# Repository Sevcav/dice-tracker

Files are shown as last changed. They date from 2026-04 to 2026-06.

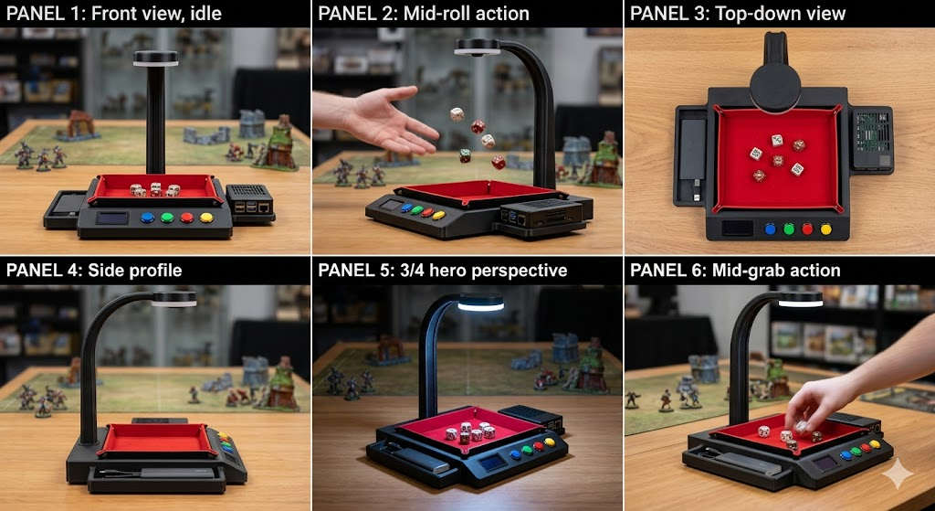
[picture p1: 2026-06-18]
docs/Concept.png

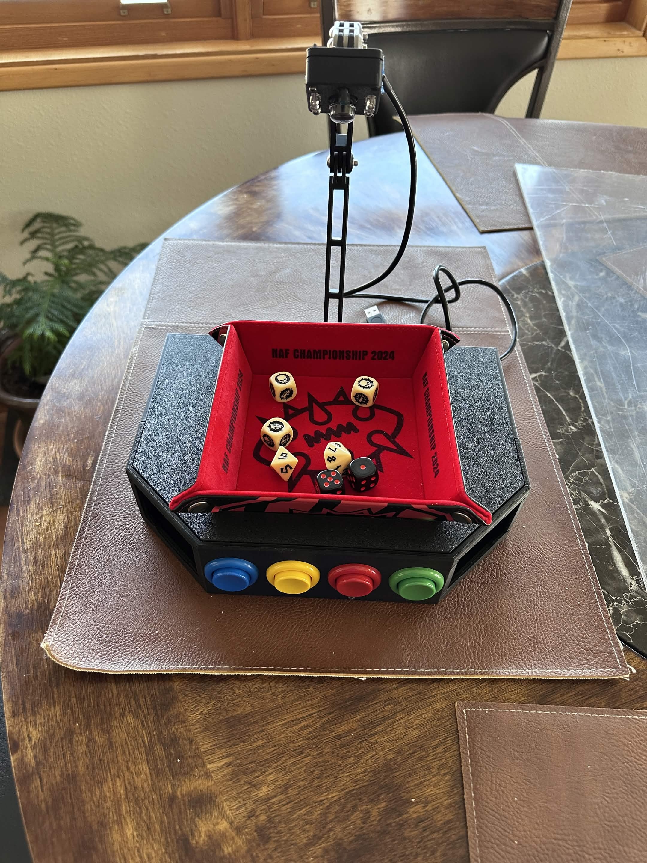
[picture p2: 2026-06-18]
docs/Completed Rig.jpg

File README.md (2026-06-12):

# Blood Bowl Dice Tracker

A portable dice-roll capture rig for Blood Bowl games and tournaments.
Players roll into a felt tray; a camera reads the dice with a YOLO model;
the rolling player confirms with a button; every roll is logged to a
database. At the end of the game you get a per-player, per-face dice
record (and the statistical proof that your dice really were cursed).

**Target hardware:** Raspberry Pi 4B + Arducam B0205 IR USB camera in a
3D-printed two-tier rig with 4 arcade buttons and 2 OLED displays.
Currently developed and validated on a Windows PC bench rig.

## How it works

1. `dice_tracker.py` watches the tray. A combined 27-class YOLOv11n
   model reads **block dice, d6, and d16 in one inference** — the dice
   type is identified automatically from the detected faces.
2. When the dice settle (stable count + stable labels), the read locks
   and the border flashes green. Low-confidence reads are flagged with
   an orange `?` — nudge that die and it re-reads in place.
3. Confirm logs the roll to SQLite under the active player. Reject saves
   the frame (with your correction) as future training data.
4. The phone web UI (`http://<rig-ip>:5000/`) shows the live read,
   switches dice type manually if ever needed, and serves the post-game
   record: face tallies per player, roll log, corrections, CSV export.

## Quick start (PC bench)

```
pip install -r requirements.txt
python dice_tracker.py            # alignment overlay -> SPACE -> play
python webapp.py                  # standalone review server (no camera)
python eval_harness.py --type block   # measure real per-die accuracy
```

Every camera session starts with two built-in pre-flights: an IR-mode
self-check (the models only know IR frames) and a tray-alignment overlay
(the models only know the calibrated perspective).

## Key documents

- **`DESIGN.md`** — single source of truth: hardware specs, detection
  architecture, locked decisions, lessons learned.
- **`HANDOFF.md`** — current state + next priorities for a new session.
- **`SETUP.txt`** — the original settle-then-confirm UX intent.

## Training

Labeling in Roboflow (free tier), training local via Ultralytics
(`training/train_all.py`, YOLOv11n). `training/merge_datasets.py` builds
the combined 27-class dataset from the per-type projects. Models export
to ONNX and transfer to the Pi by SCP (binaries are not committed).
Retraining policy: a new model must hit **mAP@50 ≥ 92%** on held-out
validation before it replaces production.

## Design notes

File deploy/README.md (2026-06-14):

# Raspberry Pi deployment

Move the tracker off the bench PC onto the portable rig. The Pi runs the
**torch-free** path automatically — same app, same logic, light deps.

## What makes the Pi path work

`inference_backend.py` picks the backend at import:
- **PC**: ultralytics + supervision (torch) — unchanged dev experience.
- **Pi**: `onnx_backend.py` — pure onnxruntime + numpy. Custom YOLOv11
  decoder, agnostic NMS, an IoU tracker (ByteTrack-equivalent) and a box
  smoother. Verified **bit-for-bit identical** detections to the
  ultralytics path on banked frames (2026-06-14).

`hardware.py` adds the 4 buttons / 4 LEDs / 2 OLEDs against the locked
pin map (DESIGN.md). It is a silent no-op when gpiozero/luma are absent,
so the same code runs on the PC.

## Headless operation (no monitor — the design)

The rig is a sealed box; the **phone is the only screen**. On the Pi,
dice_tracker runs HEADLESS automatically (no `$DISPLAY` and/or the onnx
backend) — no OpenCV window ever opens. Control + alignment happen on the
phone, plus the physical GPIO buttons:

- **Alignment:** open `http://dicetracker.local:5000/align` on the phone.
  It shows the live camera feed with the green tray outline; adjust the
  arm until they match, tap **Confirm alignment**. (Always step one — the
  model only knows the calibrated perspective.)
- **Live view + control:** the main phone page shows the live read and the
  dice-type / player controls; Reject / Undo / Confirm are available from
  the phone, and the arcade buttons do the same.
- `--gui` forces the dev preview window on a PC with a display; `--headless`
  forces headless anywhere.

## First bring-up

1. On the PC, push the latest code + the deployed model:
   ```
   git push                       # already done from the PC
   ```
2. On the Pi:
   ```
   git clone https://github.com/Sevcav/dice-tracker.git   # or git pull
   cd dice-tracker
   bash deploy/setup_pi.sh
   ```
   The script: apt deps, enables SPI, builds a venv with
   `requirements-pi.txt`, verifies `BACKEND == onnx`, sets the
   `dicetracker.local` mDNS hostname, lists camera devices.
3. Copy the model if not in git (ONNX is gitignored):
   ```
   scp training/models/combined.onnx        sevcav@dicetracker.local:~/dice-tracker/training/models/
   scp training/models/combined.onnx.json   sevcav@dicetracker.local:~/dice-tracker/training/models/
   ```
4. Run (headless is automatic on the Pi):
   ```
   . .venv/bin/activate
   python dice_tracker.py
   ```
   Then on the phone:
   - `http://dicetracker.local:5000/align` → align the camera, Confirm
   - `http://dicetracker.local:5000/` → live read + controls

## Autostart at boot (optional)

```
sudo cp deploy/dice-tracker.service /etc/systemd/system/
sudo systemctl enable --now dice-tracker
journalctl -u dice-tracker -f      # watch logs
```

## Checklist when something's off

- `python -c "import inference_backend as b; print(b.BACKEND)"` must print
  `onnx`. If it prints `ultralytics`, torch leaked into the venv — the Pi
  will try to load torch and choke.
- Buttons/LEDs dead? `python hardware.py` prints GPIO/OLED availability and
  the pin map; check the user is in the `gpio`/`spi` groups.
- OLEDs blank? Confirm SPI is enabled (`ls /dev/spidev*`) and both CE0/CE1
  are wired.
- Camera not found? `v4l2-ctl --list-devices`; the USB camera (not the
  dead CSI ribbon) is the path.
- Reads bad? It's almost always alignment or day-mode — the startup
  self-checks catch both; match the green outline and confirm IR mode.

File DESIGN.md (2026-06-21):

# Blood Bowl Dice Tracker — Design Document

**Last updated:** June 15, 2026
**Status:** **LIVE ON THE PORTABLE PI RIG (headless).** The synthetic-data
retrain shipped (live: block 100% / d6 100% / d16 85%, pow 60%→100%) and
the whole system now runs on the Pi off-camera through the torch-free ONNX
backend — buttons, LEDs, dual OLEDs all confirmed. Currently polishing the
first live run (d16 settle fix + LED dimming, pushed 2026-06-15, awaiting
final live confirm). **See HANDOFF.md "LIVE RIG BRING-UP" for the exact
resume point.** Models: production `combined.onnx` = full-rotation
tray-crop 27-class YOLOv11n + `combined.onnx.json` sidecar (tray_crop,
pad 8 / pad_bottom 40). Pi: `dicetracker`@192.168.68.85, user `sevcav`,
run via `cd ~/dice-tracker && . .venv/bin/activate && python dice_tracker.py`.

*(Prior bench-rig status, still true: auto dice-type detection, settle-race
fix COUNT_STABLE_FRAMES, IR self-check + alignment pre-flights.)*
SQLite database + phone web app live: dice-type control, live read
display, post-game corrections (dropdowns), CSV export, and the
**BB3-style end-of-game dice record** with icons drawn from the actual
dice. All committed + pushed. See `HANDOFF.md` for the session hand-off
prompt, and memory entity `BB Dice Tracker Current State 2026-06-12`.

**Retraining policy (locked):** Any retrain (block / d6 / d16) using accumulated rejection frames must still achieve **mAP ≥ ~92%** (block baseline) on the held-out validation set before its ONNX replaces the production model. If retrain regresses below baseline, do not deploy — revert and try a different mix of training data.

**Combined model + auto dice-type detection (deployed 2026-06-11):**
manual dice-type switching proved unworkable in play (players alternate
block/d6 constantly; a wrong-model read logs confident garbage). Cheap
discriminators failed offline (confidence-vote 73%, brightness
inconclusive), so the original single-combined-model plan was revived:
the three datasets were merged (`training/merge_datasets.py`, 1126
images, 27 classes) and one YOLOv11n trained locally. Per-type mAP@50 vs
the separate models: block 92.4% (−3.7, still over the 92% bar), d6
98.4% (−1.1), d16 87.4% (−1.1). `dice_tracker.py` defaults to **auto
mode** (`combined.onnx`): dice type is derived from the detected face
labels per roll; per-type models remain as manual overrides (keys
B/D/X, phone buttons). Pi cost unchanged — one nano inference per frame.

**Session startup rule (locked 2026-06-11):** **Camera alignment is ALWAYS the first step of any camera session.** Moving the rig moves the camera, and the models only know the calibrated tray perspective in `tray_roi.json`. Never score, capture, or log rolls before alignment is confirmed. On the PC (GUI) this is the on-screen green-outline overlay → SPACE; on the **headless Pi** it is the phone alignment screen (`/align`: live feed + green outline → Confirm). Standalone `align_camera.py` remains for bench work.

**Headless rule (locked 2026-06-14):** **The production rig has NO monitor — it is a sealed box and the phone is the only screen.** `dice_tracker.py` runs headless automatically on the Pi (no `$DISPLAY` / torch-free onnx backend): no OpenCV window ever opens; alignment, live read, and Reject/Undo/Confirm are all on the phone, alongside the 4 GPIO buttons. The cv2 preview window is dev-only (`--gui` on a PC). Do not reintroduce a runtime dependency on an attached display.

---

## 1. Project Vision

A portable, self-contained device that captures Blood Bowl dice rolls at gaming
stores and tournaments. Players roll into a tray, the camera reads the dice,
the result is attributed to the rolling player via a dedicated button, and the
roll is logged to a database for later analysis via a web app.

**Not a livestream/replay device.** A **data capture device**.

### Core requirements

- Self-contained — no PC on the table
- Works under variable lighting (gaming store conditions)
- Powered by USB power bank for portability
- Modular 3D-printed rig (lower tier + lid + removable dice tray + power bank shelf)
- Phone connects over WiFi for the web UI

---

## 2. Production Rig Design (Active)

The production rig is a **modular two-tier design** with a removable dice tray.

### Architecture

| Tier | Purpose |
|---|---|
| **Lower tier** | Electronics enclosure — Pi, buttons, LEDs, OLEDs, camera mount |
| **Lid** | Sits on top of lower tier, has tray opening + posts hanging down to bolt to lower tier |
| **Dice tray (removable)** | Drops into the lid's tray opening, felt-lined, removable for felt application and Pi access |
| **Power bank shelf** | External, attaches to rear of rig |

### Outer Dimensions

- **Outer footprint:** 260 × 190mm (W × D) with 55 × 55mm chamfered front corners
- **Lower tier height:** 60mm
- **Lid height:** 60mm
- **Total stack height:** 120mm + tray protrusion

### Material

- **PETG** throughout (heat resistance for hot summer venues)
- 4mm wall thickness on all major shells

---

## 3. Component Status

| Component | Status | Notes |
|---|---|---|
| **Lower tier** | ✅ Modeled | All cuts complete: buttons, LEDs, OLED windows, camera mount |
| **Lid (with posts)** | ✅ Modeled | Tray opening + 4 hanging posts with captive M4 nuts |
| **Dice tray (removable)** | ⏳ To design | Felt-lined insert, drops into lid tray opening |
| **Camera base plate** | ⏳ To design | Replaces MakerWorld Camera_Base bottom; bolts into lower tier rear detent |
| **Power bank shelf** | ⏳ To design | External rear shelf for UGREEN power bank |
| **Camera cradle** | 🔧 Blocked | Need Arducam in hand for pocket sizing |
| **Photoresistor light shield** | ✅ Printed | Black cover over the B0205 photoresistor forcing IR mode. NOTE: frame analysis 2026-06-11 found the May 13 *morning* session ran in day mode (color cast) while the afternoon ran in IR — verify the shield fully seals against bright-room light |
| **Bench prototype tray cradle** | ✅ Printed | Standalone test, validated soft-tray support concept |
| **Bench prototype arm foot** | ✅ Printed | Bridges over cradle back posts; captive nuts; friction-fit |
| **Camera_Base + Camera_Link** | ✅ Printed | From MakerWorld 627829, will be re-used for production rig |

---

## 4. Production Rig — Detailed Specs

### 4.1 Lower Tier

| Spec | Value |
|---|---|
| Outer footprint | 260 × 190mm with 55mm front chamfers |
| Wall thickness | 4mm |
| Height | 60mm |
| Front face: button holes | 4 × Ø27.78mm |
| Front face: LED holes | 4 × Ø8mm (for 7.5mm snap-in bezels) |
| Button positions (X) | ±56.7 and ±18.9mm |
| Button vertical (Z) | ~33mm centered |
| LED positions (X) | Same as buttons |
| LED vertical (Z) | ~9mm |
| Both chamfered corners | OLED window (62.53 × 40.28mm) + PCB recess (3mm deep) |
| Rear face: camera mount detent | 50 × 50 × 3mm pocket on outside |
| Rear inside wall: nut pockets | 4× hex pockets, 0.25mm deep, on inside of rear wall |
| Rear bolt clearance | 4 × Ø4.5mm holes through rear wall |
| Camera mount bolt path | Outside (camera plate) → through 4.5mm clearance → into captive nut on inside |

### 4.2 Lid

| Spec | Value |
|---|---|
| Outer footprint | 251.44 × 181.44mm with chamfered front corners (matches lower tier outline) |
| Wall thickness | 4mm |
| Height | 60mm |
| Tray opening (visible from top) | 160mm wide × 130mm deep |
| Tray opening lip | 4mm wide step around perimeter, 2mm deep recess |
| Tray opening biased toward rear | Yes |
| Posts (4) | Round Ø10mm columns hanging from lid underside |
| Post length | 54mm (engages 2mm into lower tier floor pocket) |
| Post positions | Front: (±110, -30); Rear: (±115, +85) |
| Post captive nut | M4 hex pocket at bottom of each post (3.4mm deep) |
| Post bolt clearance | Ø4.5mm hole through center of each post |
| Bolt entry | From bottom of lower tier (countersunk) |

### 4.3 Dice tray (still to design)

| Spec | Value |
|---|---|
| Outer flange (sits on lid lip) | 159.7 × 138.7mm × 2mm tall |
| Tray body (drops through lid) | 153.7 × 132.7mm |
| Total height | ~52mm |
| Wall thickness | 4mm |
| Floor thickness | 3mm |
| Inner draft | 5° outward (top wider) |
| Felt lining | Self-adhesive felt sheet, applied after print |

### 4.4 Camera base plate (still to design)

| Spec | Value |
|---|---|
| Plate size | ~50 × 50mm (sized to fit in 50×50mm rear detent of lower tier) |
| Plate thickness | 3mm (recessed flush into detent) |
| Top mating | Hinge clevis matching Camera_Link's M4 hinge |
| Bottom mating | 4× M4 clearance holes matching lower tier captive nut pattern |

### 4.5 Power bank shelf (still to design)

| Spec | Value |
|---|---|
| Power bank dimensions | 160.5 × 81 × 26.5mm (UGREEN Nexode) |
| Shelf attachment | Snap-fits or bolts to rear face of lower tier |
| Cable management | Routes USB-C power to rear of rig into Pi |

---

## 5. Detection Software

### Pipeline (current — YOLO architecture)

1. **Frame capture** — `capture_frames.py` saves raw 1280×720 frames in IR mode
2. **Stability tracker** — wait for dice to settle (no motion) — to be carried over from old code
3. **YOLO inference** — single ONNX model produces per-die `(class, x, y, w, h, conf)` boxes
4. **Player attribution** — handled at the rig (see Player attribution section)

The legacy rule-based pipeline (mask → contours → watershed → CNN classifier)
has been **archived** under `archive/legacy_rule_based_detector/`.
See that folder's README.md for why it was abandoned.

### Dice scope

| Die | Detection | Classes | Status |
|---|---|---|---|
| Block dice (cream) | YOLO | 5 (pow, push, both_down, player_down, stumble) | ✅ Labeled, training overnight 5/4 |
| BB d6 (black) | YOLO | 6 (1-5, bb_logo) | ⏳ After block validates |
| D16 (cream, trapezohedron) | YOLO | 16 (1-16) | ⏳ After d6 — injury rolls |
| D8 (scatter) | 📱 Manual entry on phone | — | — |
| D3 | 📱 Manual entry on phone | — | — |

**Single combined model is preferred** — one YOLO model with all classes vs.
separate models per die type. Easier deployment, single inference call. We
will train block-only first to validate the workflow, then expand the same
model to include d6 then d16.

### Camera angle

Set **empirically** by functional constraints (full tray visible + arm clear
of rolling area), not to a fixed degree number. As-built geometry comes out
shallow / near-overhead — top faces dominate each die crop, side faces are
minimized. The "~35° forward bank shot" figure from earlier docs was an
estimate that did not match the as-built rig.

### Lighting / IR

Production lighting strategy is **forced IR mode** on the Arducam B0205.
This eliminates color/white-balance variability across gaming store
conditions, and IR LED illumination dominates ambient light from windows
and store fluorescents — making the dice appearance consistent regardless
of time of day.

The B0205's IR mode is **photoresistor-controlled only** (no software
toggle available). A 3D-printed light shield over the photoresistor will
force IR mode on regardless of room brightness — see Section 3 component
list.

> **VERIFIED 2026-06-21 (UVC enumeration on the Pi).** `v4l2-ctl
> --list-ctrls-menus` and `uvcdynctrl -c` against `/dev/video0` return only
> the stock OV2710 UVC control set (brightness, contrast, saturation, hue,
> white balance, gamma, gain, power-line-freq, sharpness, backlight
> compensation, auto-exposure, exposure time). **No IR / night / day /
> IR-cut control and no vendor extension units exist.** There is therefore
> no software path to force the IR-cut filter — confirming this decision.
> Do not re-open "replace the camera software to force IR"; the firmware
> does not expose the filter. The day-mode self-check is healthy and **auto-white-balance is load-bearing
> for IR detection.** Measured + VISUALLY CONFIRMED 2026-06-21 (tracker
> stopped, `/dev/video0`, rig in a sunlit window, shield sealed): saved
> frames `sun_awb_on.jpg` / `sun_awb_off.jpg` show the SAME dark IR scene —
> no daylight floods the sensor (shield works). With **AWB ON** the raw
> violet IR cast is corrected to near-neutral → `color_dev` **3.58** (reads
> IR, correct). With **AWB OFF** the identical scene goes strongly purple
> (OV2710 raw channel imbalance in near-IR) → `color_dev` **11.84** → false
> day-mode, against the `DAY_MODE_DEVIATION = 8.0` threshold.
>
> Therefore: **do NOT pin `white_balance_automatic=0`** — AWB-on is what
> keeps IR frames neutral; disabling it BREAKS the day-mode check. Leading
> hypothesis for the intermittent real-world day-mode trips: the live
> re-check (`dice_tracker.py` ~L753, `IR_CHECK_INTERVAL`) sampling during a
> window where **AWB has not yet converged** (just after open, or after a
> lighting change) and briefly seeing the raw violet cast. To confirm: log
> `color_dev` + save the frame on every re-check trip over a real session.

### Roboflow + training workflow

- **Dataset:** Roboflow Public/Free workspace `bbdicetracker`
- **Project:** "My First Project" (Object Detection, public)
- **Capture script:** `capture_frames.py` saves 1280×720 frames to
  `capture_sessions/<timestamp>/`
- **Labeling:** Roboflow web UI, manual bounding boxes per die
- **Preprocessing:** Auto-Orient, Resize 640×640
- **Augmentation:** Horizontal flip, ±15° rotation, ±20% brightness,
  ≤1px blur, ≤1% noise
- **Train/val/test split:** 70/20/10 (112/32/16 of the 160 frames)
- **Model:** Roboflow 3.0 Object Detection (Fast variant)
- **Checkpoint:** Fine-tune from MS COCO
- **Deployment:** ONNX export → `classifier/` folder → ONNX Runtime on Pi
  (already validated)

### Player attribution

- 4 buttons on rig: **P1 Confirm**, **P2 Confirm**, **Reject**, **Undo**
- Whoever pressed **their** confirm button = the rolling player
- No turn tracking on rig — that lives in the web app
- Phone web app selects dice type (Block / D6 / D16) before each roll

### Correction flow (LOCKED 2026-05-13)

The rig has **4 buttons total**. There is **no keyboard, no number-pad,
no menu navigation** during play. Players will abandon any correction
tool that takes more than a button press. This drives a hard design
principle: **prevention over correction**.

**Pre-confirm correction tools (real-time, frequent use):**

1. **Nudge to re-read** — player physically nudges a misread die.
   `dice_tracker.py` detects per-die motion of more than
   `NUDGE_PIXEL_THRESHOLD = 20px` between consecutive frames and
   automatically releases the settle lock back to "watching" so the
   model re-evaluates. The rest of the roll is preserved; only the
   nudged die gets re-read. Built and validated.
2. **OLED uncertainty markers** *(planned)* — low-confidence labels
   shown with a `?` so the player's attention is drawn to questionable
   dice. High-confidence labels show clean. The OLED's role is to
   make wrong-reads obvious BEFORE the player confirms.
3. **Reject button** — explicit "this read is wrong" before confirm.
   Saves the frame to `retrain_candidates/<type>/` for future model
   improvement.

**Post-confirm correction tools (emergency, rare use):**

4. **Undo button** — removes the LAST logged roll. Player must catch
   the mistake immediately (within ~1 roll). If they realize N rolls
   later, Undo would lose the rolls in between.
5. **Phone web app post-game session review** *(planned, post-MVP)* —
   the phone app's session export/review screen will allow editing
   historical mis-logged rolls. This is the only path for corrections
   discovered late. It is explicitly NOT a real-time tool — it's run
   after the game when speed doesn't matter.

**What we deliberately did NOT build:**

- No keyboard-driven edit flow (`E` to enter manual values for last
  roll) — violates the 4-button constraint and the "no menus" rule.
- No mid-game phone-based correction — adds a context switch that
  slows play; players abandon the tool.
- No "undo by roll number" — too complex for buttons; ambiguous which
  intermediate rolls to preserve.

The cost of this constraint: occasional wrong rolls slip into the log
and aren't caught until later. That is acceptable as long as the
model + OLED-warning + nudge UX keeps the slip rate low. If real-world
play shows the slip rate is too high, the fix is more training data
(retrain to a higher mAP) or richer OLED warning — NOT a richer
correction UI on the rig.

### Accuracy evaluation (added 2026-06-11)

`eval_harness.py` measures **real per-die accuracy** against keyed-in ground
truth, using the exact production detection stack from `dice_tracker.py`.
Per roll: settle → console prints the read (dice numbered left→right,
matching `[n]` overlays in the window) → user types truth (ENTER = correct)
→ clear tray → repeat; `q` prints + saves the report
(`eval_sessions/eval_<type>_<ts>.json/.csv`). Misread frames are saved to
`retrain_candidates/<type>/eval_miss_*.jpg/.json` **with ground truth
attached**, ready for relabeling. The report includes per-die accuracy with
a 95% Wilson CI, roll-level accuracy, per-class recall, confusion pairs,
detection-count errors, and how many rolls were captured in day mode.

Target: ≥50 rolls per dice type (~±3-4% CI at 3 dice/roll). The previous
"86% confirm rate" was 6/7 rolls — 95% CI of 49-97%, not a usable number.

**First block eval (2026-06-11, 50 rolls, 144 dice, all IR):**

- Per-die accuracy 86/96 = **89.6%** (95% CI 81.9–94.2%) on count-correct
  rolls; roll-level 79.4%.
- **Dominant failure: missed dice** — 16/50 rolls lost dice (23 dice never
  read). ROOT CAUSE FOUND: a settle-logic race, not model blindness —
  14/16 saved miss-frames had ALL dice detectable at standard settings on
  the very frame that settled. A detection flickering in/out at the conf
  threshold let the roll settle during an "out" frame. **Fixed** by
  requiring the detection count to hold constant for
  `COUNT_STABLE_FRAMES = 10` consecutive frames before settle (restores
  the count-stability requirement the legacy DiceStabilityTracker had).
  Needs re-eval to confirm.
- Weakest class: **pow, 64% recall** (7/11), confused with stumble ×3.
  More pow training data wanted at next retrain.
- **Confidence threshold 0.85 validated for OLED `?` markers**: 8/10
  wrong reads fell below 0.85; only 18/86 correct reads did.
- The 2 miss-frames not recovered at conf 0.40 full-frame WERE recovered
  by a tray-ROI crop — keep tray-crop inference in the back pocket as an
  accuracy lever.

**Re-eval after settle fix (2026-06-11, 25 rolls, 75 dice):**

- **Count errors collapsed: 16/50 → 2/25** (32% → 8%). Settle-race fix
  validated.
- Per-die accuracy 57/69 = 82.6% (CI 72.0–89.8%) — *lower* than session 1
  because the hard flickery dice that previously vanished as count errors
  now stay in the read and get scored. This is the honest number.
  Combined across both sessions: 143/165 = 86.7%.
- **pow recall 57%** (8/14); combined 15/25 = 60%. pow confusions go both
  directions (read as both_down ×3, stumble ×2). Every other class is
  86–97%.
- **Misread-frame experiment:** re-reading the same frames full-frame fixed
  0/10 (errors are systematic, not flicker). Tray-crop re-read flipped pow
  to CORRECT in 4 rolls — pow is distinguishable at 2× resolution — but
  broke other dice because the model wasn't trained on crops.
- **Conclusion / retrain plan:** the pow fix is RESOLUTION, i.e. retrain
  on tray-cropped data and run inference on crops. Next capture session:
  pow-heavy + wall/corner positions; build the dataset tray-cropped
  (training is local now, we control preprocessing); fold in the banked
  `retrain_candidates/block/` frames with ground truth. ≥92% mAP bar
  applies. Until then the current model stays in production — the 0.85
  OLED `?` threshold catches ~80% of its wrong reads.

Both `dice_tracker.py` and `eval_harness.py` now run two startup
pre-flights, in order:

1. **IR-mode self-check** — refuse-to-start prompt in day mode;
   `dice_tracker.py` also re-checks every ~3s during play with a red HUD
   warning if the camera flips to day mode mid-session.
2. **Camera alignment check** — overlays the saved tray-corner reference
   (`tray_roi.json`) on the live feed; adjust the camera arm until the
   tray matches the green outline, SPACE to continue. The rig moves
   between sessions and the model only knows the calibrated perspective,
   so this always runs first (standalone `align_camera.py` still exists
   for bench work).

### Database + web app (IMPLEMENTED 2026-06-11)

**`db.py`** — SQLite (`dice_tracker.db`, gitignored), short-lived
connections (safe across tracker + Flask threads):

```
games:  id, started_at, ended_at, player1_name, player2_name, notes
rolls:  id, game_id FK, roll_no, timestamp, player (P1|P2), dice_type,
        results JSON, confidences JSON, rejected, edited, raw_image_path
```

`dice_tracker.py` creates the game row lazily on the first logged roll,
inserts on confirm AND reject (rejected=1), deletes on undo, closes the
game on quit. `face_tallies()` produces THE end-of-game record:
per-player, per-dice-type face counts over confirmed rolls.

**`webapp.py`** — Flask phone UI, mobile-first, single file:

- **Live control** (`/`): dice-type buttons (Block/D6/D16) and active
  player buttons; requests flow to the tracker loop through a
  thread-safe `WebControl` mailbox; 1s status poll (state, last roll,
  roll count, day-mode warning).
- **Game review** (`/games`, `/games/<id>`): roll log with confidences +
  reject/edit flags, the face-tally record, per-roll edit (flagged
  `edited` — this is the post-game correction path from the locked
  correction flow), delete, CSV export.
- Started automatically in a daemon thread by `dice_tracker.py` on port
  5000 (`--no-web` disables). Standalone review mode: `python webapp.py`.

**HUD uncertainty markers (OLED precursor, threshold 0.85 from eval
data):** stable+confident = yellow; stable but conf < 0.85 = ORANGE with
`?` and a NUDGE hint; still settling = gray. The same three-state logic
will drive the physical OLEDs.

---

## 6. Hardware

### As-built BOM (components actually used in the rig)

- Raspberry Pi 4B in TH3D aluminum case (91 × 65 × 33mm)
- 64GB A2 microSD (upgraded from the original 32GB, which was getting full)
- Arducam 1080P Day/Night IR USB camera (OV2710 sensor) — the production
  camera; forced into IR mode by a printed lens cap over the photoresistor
- 4× WMYCONGCONG arcade buttons (verified: thread Ø26.25mm, dial Ø33mm, body
  length 62mm — using Ø27.78mm holes for print clearance)
- 4× 5mm pre-wired LEDs in 7.5mm snap-in bezels (Ø8mm holes); inline
  resistor under heatshrink on the red lead (status LEDs: P1/P2/reject/undo)
- 2× HiLetgo SPI 2.42" OLED 128×64 (SSD1309, 7-pin SPI): PCB 71×43mm, glass
  62.25×40mm, header zone 14mm at top
- UGREEN Power Bank (160.5 × 81 × 26.5mm)
- Dupont female-to-female jumper wires (OLED / button / LED GPIO wiring)
- 1-to-2 wire splitters (ground consolidation to the Pi's GND pins — see
  the Ground consolidation note below)
- M5×25mm SHCS + M5 nyloc nuts (camera arm friction joints)
- M3 + M4 screws (M4 lengths: 8/12/16/20mm) + M3/M4 nuts (case assembly)

### Optional add-on

- 7" HDMI touchscreen — on-rig display (Mediatrix MPI7002, runs at 1920×1080;
  desktop scaled to 2× for readability via labwc autostart `wlr-randr`). Handy
  for on-rig use but NOT required — the rig is normally controlled phone-only.

### Ordered but NOT used

- M4 brass heat-set inserts (kept for a future production revision)
- Bambu LED Lamp Kit 001 ×2 — was for the abandoned day-mode lighting
  strategy; the rig is **always IR** (see §6 Lighting / IR), so the lamps
  are unused
- Pre-crimped JST pigtails (5 red / 5 black) — replaced by Dupont jumpers
  + 1-to-2 splitters (wrong connector type for the OLED pin strip anyway)

### Equipment (tools / spares, not consumed in the build)

- Bambu P1S 3D printer
- Pi 3B (spare)
- Pi Camera v2.1 with 22" ribbon (CSI port non-functional on this Pi 4 —
  superseded by the USB Arducam)
- USB camera (test only, not the production camera)

### Wiring notes

- **OLEDs (SSD1309, SPI, 7-pin):** All 7 pins used. Two OLEDs share CLK/MOSI/DC/RES/VCC/GND; differentiated by CE0 (GPIO 8) and CE1 (GPIO 7). Requires ~20 female-to-female dupont jumper wires — **not yet on hand**.
- **LEDs:** Pre-wired with resistor inline under heatshrink on red lead. Connect red → GPIO, black → GND directly. No additional resistors needed.
- **Arcade button switches:** PCB-mount microswitch (pin legs, not spade). Use COM + NO only (ignore NC). Solder wires direct to pins or friction-fit female dupont. 2 wires per button × 4 buttons = 8 connections.
- **GPIO allocation:** OLEDs ×2 = 6 pins; Buttons ×4 = 4 pins; LEDs ×4 = 4 pins. Total = 14 of 28 available GPIOs.
- **Library:** luma.oled (pip install luma.oled) — native SSD1309 SPI support.

#### LOCKED GPIO pin map (2026-06-13, BCM numbering)

Verified software-clean (no SPI-bus collision; all plain GPIO with usable
internal pull-ups). OLEDs share the SPI0 bus, distinguished by chip-select.

| Function | BCM GPIO | Physical pin | Wiring |
|---|---|---|---|
| OLED SCLK (both) | GPIO 11 | 23 | SPI0 SCLK, shared |
| OLED MOSI/DIN (both) | GPIO 10 | 19 | SPI0 MOSI, shared |
| OLED DC (both) | GPIO 9 | 21 | shared |
| OLED RES/RST (both) | GPIO 25 | 22 | shared |
| OLED-1 CS (P1 side) | GPIO 8 | 24 | SPI0 CE0 |
| OLED-2 CS (P2 side) | GPIO 7 | 26 | SPI0 CE1 |
| OLED VCC (both) | 3V3 (NOT 5V) | 1 | shared; SSD1309 is a 3.3V part |
| OLED GND (both) | GND | 6 (any GND) | shared rail |
| Button: P1 Confirm | GPIO 17 | 11 | switch → GND, internal pull-up |
| Button: P2 Confirm | GPIO 27 | 13 | switch → GND, internal pull-up |
| Button: Reject | GPIO 22 | 15 | switch → GND, internal pull-up |
| Button: Undo | GPIO 23 | 16 | switch → GND, internal pull-up |
| LED: P1 | GPIO 5 | 29 | red → GPIO, black → GND (inline R) |
| LED: P2 | GPIO 6 | 31 | red → GPIO, black → GND (inline R) |
| LED: Reject | GPIO 13 | 33 | red → GPIO, black → GND (inline R) |
| LED: Undo | GPIO 19 | 35 | red → GPIO, black → GND (inline R) |

Buttons: COM/NO only (NC unused). LEDs already have inline resistors —
no external resistor. Convenient grounds (all the same rail): physical
pins 6, 9, 14, 20, 25, 30, 34, 39.

OLED VCC = **3V3 (pin 1)**, never 5V. GND = any ground pin above.

#### Ground consolidation (REVISED 2026-06-14 during wiring)

**ACTUAL APPROACH BEING WIRED: grounds go DIRECT to the Pi's 8 ground
pins using 1-to-2 Dupont splitters — the breadboard is NOT needed for
grounds.** 10 grounds (2 OLED + 4 button + 4 LED) vs 8 Pi ground pins
(6, 9, 14, 20, 25, 30, 34, 39); the user has 1-to-2 splitters, so a few
pins fan out to cover all 10. Rationale: for a sealed/portable rig,
direct-to-header has fewer friction joints to shake loose than a
breadboard rail, and the 8 ground pins have no other use. The ordered
breadboard becomes optional (spare, or a 3V3 rail for the two OLED VCC).

- **OLED grounds (both):** one Pi GND **pin 25** → 1-to-2 splitter →
  both OLED GNDs (pin 25 sits in the OLED signal cluster 19/21/22/23).
- **Buttons + LEDs (8 grounds):** spread across the remaining ground
  pins (6/9/14/20/30/34/39) with splitters as needed.

The breadboard option below is RETAINED as fallback / 3V3-rail use:

~10 ground wires, all **26–28 AWG Dupont-terminated**; case is already
set/printed (NO HAT — a GPIO terminal HAT stands too tall and covers the
header), stay plug-in (no cutting Dupont ends, no soldering), plenty of
internal room.

- **ORDERED 2026-06-14: REXQualis/Ambberdr 400-point self-adhesive
  breadboard** (Amazon's Choice, ~$7.19, 6-pack; 3.22×2.12×0.35"). This
  is the committed ground/3V3-bus part. Listing confirms
  the three musts: "2 Positive & Negative Power Lines on both ends" (the
  common bus), "Self-Adhesive Tape on the Back" (peel-stick mount), and
  "20-29 AWG" wire support (covers the 26–28 AWG Dupont). 170-point minis
  were REJECTED — they have no power rails (only 5-hole tie columns), so a
  10-wire bus would need bridging multiple columns.
  Wiring: stick it inside the rig; jumper any Pi GND pin
  (6/9/14/20/25/30/34/39) into a `-` power line to make it common ground;
  plug all 10 ground Duponts into it. One Pi GND pin used. The `+` line
  buses the two OLED **3V3** wires the same way (jumper from pin 1).
  Note: 400-pt rails are usually split into 2 segments/side — one short
  jumper joins the halves if you ever need >1 segment (you won't for 10).
  NEED ONE F/M jumper for the Pi-pin→rail link (female onto the Pi male
  header pin, male into the breadboard).
- **Rejected:**
  - GPIO screw-terminal HAT — covers the 40-pin header and stands too
    tall for the finished case; also needs Dupont ends cut to bare wire.
  - WAGO 221 lever-nuts — rated 24 AWG min; Dupont (26–28 AWG) too thin
    to seat. (WAGO 243 micro fits but needs cutting.)
  - 2.54mm common-bus PIN board — would work and stays plug-in, but the
    mini breadboard is cheaper/more flexible and we have the room.
- Portability caveat: breadboard rails are light friction tie-points —
  after seating, a dab of hot glue over the inserted wires (NOT solder,
  not on the rail clips) stops them backing out when the rig travels.
  Reversible with a peel.

NOTE on the generated wiring images (wiring/): the labels are verified
against THIS table, but the `wiring/gpio_wiring_diagram.png` v2 image has
one hallucinated label — "GND (Pin 7)". Physical **pin 7 is GPIO4, not a
ground.** Ignore that label and its dangling wire. This table is the
authoritative source, not the image.

### Captive nut pocket dimensions (PETG, 0.28mm gap)

| Nut | Circumscribed dia (Fusion polygon) | Flat-to-flat | Depth |
|---|---|---|---|
| M4 | 8.32mm | 7.56mm | 3.4mm |
| M5 | 9.80mm | 8.56mm | 4.1mm |

- Camera arm friction joints use M5×25mm SHCS + M5 nyloc nuts (M5×20 button heads too short — 5mm deficit at 16.5mm joint span)
- M5 bolt clearance hole: 5.7mm

---

## 7. Software State

### Pi-side stack (validated working)

- Python 3.13.5
- OpenCV 4.13.0
- ONNX Runtime 1.25.1
- Flask 3.1.1

### Code repo

- GitHub: github.com/Sevcav/dice-tracker
- Pi clones from this repo
- ONNX model transferred via SCP (binary, not committed to git)

### Repo layout (current, 2026-06-12)

```
Dice Code/
├── DESIGN.md                # This document — single source of truth
├── HANDOFF.md               # Session hand-off prompt + current priorities
├── README.md
├── SETUP.txt                # Original UX intent (settle→confirm) — still canon
├── requirements.txt
├── dice_tracker.py          # PRODUCTION app: YOLO + supervision stack +
│                            #   settle/confirm UX + DB logging + web thread
├── eval_harness.py          # Ground-truth per-die accuracy measurement
├── db.py                    # SQLite layer (games/rolls, face tallies)
├── webapp.py                # Phone web UI: live control + game record/review
├── dice_types.py            # Shared face vocabularies / type mapping
├── align_camera.py          # Standalone camera-alignment overlay
├── calibrate_tray_roi.py    # (Re)writes tray_roi.json reference corners
├── capture_frames.py        # Frame capture for labeling sessions
├── scan_capture.py          # Pre-upload capture QA (Roboflow ingest checks)
├── tray_roi.json            # Calibrated tray corners (may4 backup alongside)
├── training/                # Local Ultralytics training (RTX 4080)
│   ├── train_all.py         #   block / d6 / d16 / combined configs
│   ├── merge_datasets.py    #   builds the 27-class combined dataset
│   ├── models/              #   ONNX outputs (gitignored — SCP to Pi)
│   ├── datasets/, runs/     #   gitignored artifacts
│   └── live_detect*.py …    #   dev/debug scripts
├── capture_sessions/        # gitignored — raw frames per session
├── retrain_candidates/      # gitignored — reject/miss frames + ground truth
├── eval_sessions/           # gitignored — eval reports
├── archive/legacy_rule_based_detector/   # old pipeline, recoverable
├── Dice Images/             # Reference photos of every die face
└── Stls/                    # Rig CAD files (committed)
```

### Networking

- iPhone hotspot saved as `iphone-hotspot` connection (for game stores)
- Home WiFi (Knickerbocker on Deco mesh) saved separately as `home-knickerbocker`
- NetworkManager (`nmcli`) controls WiFi on Bookworm/Trixie
- mDNS broadcasting needed for `dicetracker.local` access from phone (TODO)
- Pi default IP on iPhone hotspot: 172.20.10.x (Apple subnet)
- Pi default IP on home network: 192.168.68.88 (DHCP, may shift)

### Tested / validated

- ✅ Pi 4 boots, SSH works
- ✅ All Python libraries import cleanly on the 64GB card
- ✅ USB Arducam captures at 1920×1080 on the PC
- ✅ Arducam IR mode engages when photoresistor is darkened
- ✅ iPhone hotspot connection saved (`iphone-hotspot`)
- ✅ Home WiFi connection saved (`home-knickerbocker`, SSID has trailing space)
- ✅ 160 frames captured of block dice in IR mode (`capture_sessions/2026-05-04_201259/`)
- ✅ All 160 frames manually labeled in Roboflow with 5 block-die classes
- ⏳ First Roboflow YOLO model training overnight 2026-05-04 → 2026-05-05

### Next up (priority order, 2026-06-12)

1. **Live eval of the combined model** per dice type
   (`python eval_harness.py --type block --model combined`, then d6/d16)
   — confirms auto mode's real per-die accuracy vs the dedicated models.
2. **Pow-heavy capture session + tray-crop retrain** — pow recall is ~60%;
   proven to be a resolution problem (tray-crop re-reads fixed 4 misreads).
   Build the dataset tray-cropped; fold in `retrain_candidates/` frames
   (they carry ground truth). ≥92% mAP bar applies.
3. **Wiring + GPIO code** for buttons / OLEDs / LEDs (luma.oled, SSD1309
   SPI ×2). OLED rendering = the three-state uncertainty logic already
   proven on the HUD and phone (yellow / orange-? / gray, threshold 0.85).
4. **Pi port**: pure onnxruntime inference path (ultralytics needs torch —
   too heavy for the Pi), mDNS broadcast for `dicetracker.local`, DHCP
   reservation or hotspot config.
5. D8/D3 manual entry flow in the web app.

---

## 8. Open Questions / Deferred Decisions

| Topic | Status |
|---|---|
| Lighting strategy | **Always IR mode.** B0205 IR is photoresistor-only (no software toggle), so a 3D-printed lens cap / light shield permanently darkens the photoresistor to FORCE IR — the mode the dice models are trained on. The day-mode self-check warning means a real fault (shield not sealing), not an acceptable state. (Bambu lamps + day-mode is NOT the strategy.) |
| Camera angle | Set empirically to satisfy "full tray visible + arm clear of rolling area" — near-overhead shallow angle in as-built rig |
| D16 detection | Deferred until block + d6 working end-to-end |
| OLED retention method | Friction / hot glue / M2 screws — TBD when OLEDs in hand |
| Phone web UI scaffold | Not started |
| Database schema | Drafted, not implemented |
| Camera cradle for Arducam | Blocked — need camera in hand for measurements |
| Cable routing strategy | External clips for prototype, internal channels for production |
| Aesthetic direction | Utilitarian for prototype; organic curves for production v2 |
| Power bank shelf attachment method | Snap-fit, screw, or magnetic — TBD |
| **Optional table touchscreen (accessory, not in-case)** | **PLAN RESOLVED 2026-06-14: a STANDALONE screen on a stand at the table, ADDITIVE to the locked design (OLEDs + buttons + phone all stay).** This sidesteps every earlier blocker: no case cutout (it's a separate desktop unit), two-player ergonomics unaffected (it's a shared "scoreboard"; per-player OLEDs still do per-player results), and battery is opt-in (unplug to fall back to phone). Candidate: **ELECROW 7" 1024×600 IPS capacitive, with acrylic stand (~$52.99)** — the "with stand" SKU, not the bare $45.99 one. Connects via 3 ports on the board's left edge: Display→Pi HDMI, Touch→Pi USB, and a DEDICATED Power port → power it from the power bank directly (NOT through the Pi, so it can't brown out the Pi/camera). SOFTWARE = ~free: a boot kiosk launcher opening a browser to `localhost:5000` (the existing web app: live read, dice switching, BB3 roll record). Does NOT touch dice/detection code. Build it AFTER the rig is proven end-to-end with OLEDs+phone. **Vendor notes (confirmed on the listing):** (a) MUST power via the dedicated Power port — powering through the USB-touch port makes the touchscreen insensitive/unusable, and the speakers need the power port at >=80% volume; (b) screen and Pi are independently powered ("RPi cannot be powered on by powering the screen") — good, this is what protects the Pi/camera; (c) Pi 4 on Bullseye+ needs `dtoverlay=vc4-kms-v3d` in config.txt (handle in kiosk setup). Ships complete with stand, both cables, adapters, screws. |

---

## 9. Known Lessons / Misconceptions

- **Cradle ≠ production base.** The 200×200 cradle was a standalone bench
  test, not the foundation of the full rig.
- **Pi camera ribbon hardware appears dead** on the current Pi 4 — using USB
  camera path instead. Will not pursue ribbon further.
- **PyTorch is too big for the Pi.** ONNX Runtime is the runtime path; PyTorch
  stays on Windows for training only.
- **Apostrophes and `$` in WiFi credentials** broke `nmcli` — needed single
  quotes in shell, and full key-mgmt declaration.
- **wpa_supplicant.conf is ignored on Bookworm/Trixie** — NetworkManager is
  in charge. All WiFi config goes through `nmcli`.
- **STL external data** — PyTorch ONNX export creates a `.onnx.data` sidecar
  for large models. Both files must be transferred together.
- **Deco mesh routers can block new devices** — single SSID for both bands
  caused initial connectivity issues; ethernet was the most reliable path
  for initial setup.
- **Captive nuts beat heat-set inserts** when inserts haven't shipped yet,
  and captive nuts are stronger anyway (steel vs brass).
- **Print pause at the right layer** is critical for captive nuts — too late
  and the pocket caps over; too early and pocket walls haven't formed yet.
- **OLED PCB has a header strip** at the top — total height includes 14mm
  header zone above the active glass area. Account for this when sizing
  display windows.
- **OLED requires inside-out mounting** — PCB sits on inside of shell wall,
  glass protrudes outward through the through-window. Solder pins on PCB
  back protrude 2mm and need clearance.
- **Bumped lower tier height to 60mm** because OLED at 39.78mm tall plus
  4mm floor + 4mm top wouldn't fit in original 50mm box.
- **PCB recess depth dictates wall thickness** — initially considered 6mm
  walls for outside pocket, but moving to inside-mounting kept walls at 4mm.
- **OLED through-window goes glass-only** — header strip stays inside the
  box, only the glass + active display protrudes through the window cut.
- **Arcade button switches are PCB-mount** — pin legs not spade tabs. Solder direct to COM + NO. NC unused.
- **LEDs have inline resistor** under heatshrink on red lead — no external resistors needed.
- **Female-to-female dupont jumpers still needed** for OLED wiring — pre-crimped JST pigtails are wrong connector type for OLED pin strip.
- **M5 captive nut pocket** — circumscribed 9.80mm, flat-to-flat 8.56mm, depth 4.1mm at 0.28mm gap. Confirmed by test print.
- **Camera arm requires M5×25mm** — M5×20mm button heads are 3.3mm too short for the 16.5mm friction joint. Use M5×25 SHCS instead.
- **B0205 (Arducam UC-A53) IR is photoresistor-controlled only** — no software/UVC control of the IR LEDs or IR-cut filter. The 6 IR LEDs only activate in genuinely dark ambient conditions. Software-controlled IR is **not possible** on this unit. **Solution: a 3D-printed lens cap / light shield over the photoresistor permanently forces IR mode regardless of room brightness — IR is the mode the dice models are trained on.** (Earlier "Bambu lamps + day-mode" idea is abandoned: the models are IR-only, so day-mode reads degrade — always IR.)
- **B0205 spec lists 1m minimum focus** — but the lens is in fact adjustable to focus at ~12 inches once the locking ring is loosened. Confirmed empirically by getting a sharp image at the actual rig working distance.
- **B0205 lens locking ring is partially obstructed by the IR LED ring** — adjustment is possible but tight. Do NOT force it. Loosen with care; replacement lens would require desoldering LEDs.
- **Camera angle is empirical, not a target** — earlier "~35°" figure was wrong for the as-built rig. The functional constraints (full tray + arm clear of rolling area) drive the angle, and what comes out is shallow / near-overhead. Always measure as-built rather than declaring a degree number.
- **Wide-angle lens has heavy barrel distortion + edge softness** — center is sharp, edges warped. Acceptable for CNN training because per-die crops are small relative to the distortion field, but training data must include dice in many tray positions so the CNN sees the full distortion range.
- **35° camera angle would have made side faces visible enough to confuse the CNN** — at the actual shallow angle, top faces dominate each die crop. This was a lucky outcome of letting functional constraints drive the angle instead of picking a number.
- **Rule-based detector failed in IR mode** — `find_tray_roi` required a saturated red tray; `_mask_dice` had a polarity bug that flooded the combined mask with white. Tuning thresholds for a new lighting/camera/distance was a losing fight. Pivoted to a YOLO object detector trained via Roboflow. Old code is in `archive/legacy_rule_based_detector/`, recoverable.
- **YOLO replaces both detection AND classification** — one model outputs labeled bounding boxes per die in a single inference. The previous architecture (rule-based detector → per-die crop → MobileNetV3 classifier) is gone. Simpler runtime, less code, more robust.
- **Tray ROI calibration is still useful but not strictly required** — `calibrate_tray_roi.py` writes a JSON file with the 4 tray corners. YOLO can search the full frame, but cropping to the tray region speeds inference and reduces false positives outside the tray. Currently archived; may be revived later as an inference-time optimization.
- **Roboflow Public/Free workspace is fine for this project** — $60/mo credits, 250k image cap, free fine-tuning of small YOLO variants, free ONNX export. Public Universe sharing is acceptable since the data is dice on a felt tray. **Frames are uploaded full-frame** (background workspace visible at edges); for any future privacy concern, crop to tray ROI before upload.
- **Always check class count BEFORE clicking "Create Version"** — a single typo class (`Pow` vs `pow`, etc.) splits training data across two labels and silently degrades model accuracy. Caught one such typo in the first labeling session via the "Source Images: Classes: 6" mismatch on the Versions wizard.
- **Roboflow defaults are not optimal** — first wizard suggested 100% train / 0% valid / 0% test (no overfitting check), and 512×512 resize (YOLOv8 native is 640×640). Always edit the train/test split and the resize step before clicking Create.
- **Manual labeling 160 frames in one session is feasible** — took the user one sitting. SAM auto-labeling was *not* used because it labels generic objects without class semantics; manual labeling was actually faster end-to-end given that you'd have to re-confirm every box anyway.
- **Single combined YOLO model > separate models per dice type** — block / d6 / d16 will all share one model with combined classes (5 + 6 + 16 = 27 classes when fully expanded). Easier deployment (one ONNX file), single inference call, retrains include all dice types together.
- **IR mode must be VERIFIED, not assumed, even with the light shield printed.**
  Frame analysis (2026-06-11) of the May 13 reject frames: the morning frames
  were day-mode (warm color cast), the afternoon frame matched the IR
  training frames. The camera silently flipped lighting regimes mid-day.
  The models were trained on IR frames only — day-mode frames are
  out-of-distribution and degrade accuracy. Now guarded by a self-check in
  `dice_tracker.py` + `eval_harness.py` (see below).
- **IR check calibration (measured in-tray, 2026-06-11):** mean of |R−G|,
  |G−B|, |R−B| inside the tray ROI: true IR = 4.0-5.2 (chroma noise on the
  tray's high-contrast graphics), day mode = ~10.8-11. Threshold 8.0.
  Measure INSIDE the tray (via `tray_roi.json`, scaled to capture
  resolution) — ambient lamp spill on the floor inflates the global-frame
  number (an IR frame measured 5.4 global with a lamp on, and 25 during the
  transitional state right after plug-in). Auto-exposure takes ~2s to
  settle after camera open and reads high during settling — warm up 2s and
  take the median of 5 probes before judging.
- **The B0205 takes a few seconds to drop into IR mode after plug-in** —
  the first frames out of a freshly connected camera can be full day-mode
  color even in a dim room. Never judge lighting from the first frame.

---

## 10. Decisions Locked

### Hardware geometry
- ✅ Lower tier 260 × 190mm with 55mm front chamfers, 60mm tall, 4mm walls
- ✅ Lid matches lower tier outer footprint, 60mm tall, 4mm walls
- ✅ Tray opening in lid: 160 × 130mm with 2mm × 3-4mm wide perimeter lip
- ✅ Lid mounted to lower tier with 4× Ø10mm posts hanging down + M4 captive nuts + bolts from below
- ✅ Removable dice tray drops into lid pocket (felt-lined)
- ✅ Camera base plate replaces MakerWorld Camera_Base; mounts in 50×50mm rear detent
- ✅ Camera arm: re-use Camera_Link from MakerWorld 627829
- ✅ Power bank external on rear shelf

### Detection
- ✅ Block dice + BB d6 + D16 (single combined YOLO model); D8/D3 manual entry
- ✅ D16 needed for injury rolls (not kickoff)
- ✅ No turn tracking on rig — pure data capture
- ✅ Camera angle: set empirically by functional constraints (full tray visible, arm clear of rolling area) — not a fixed degree target
- ✅ Production rig direction: utilitarian for prototype, organic v2 later
- ✅ **Architecture: YOLO object detector via Roboflow** (replaces former rule-based detector + MobileNetV3 classifier). Trained on labeled IR-mode frames; ONNX-deployed on Pi.
- ✅ Lighting strategy: forced IR mode (photoresistor light shield). No software toggle on B0205, so a 3D-printed shield permanently darkens the photoresistor.
- ✅ Capture/labeling workflow: `capture_frames.py` → upload to Roboflow → manual bounding boxes → ONNX export → SCP to Pi.
- ✅ Train block first, then expand same model to d6, then d16.

### Bench prototype (validation only — not production)
- ✅ Tray cradle 200×200×5mm with 4 corner posts (15×15×50mm)
- ✅ Arm foot bridges back two posts of cradle (230 × 40 × 15mm)
- ✅ Both validated by printing

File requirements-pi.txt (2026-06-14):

# Blood Bowl Dice Tracker — Raspberry Pi runtime (torch-free).
#
# The PC requirements pull in ultralytics + supervision, which depend on
# torch — too heavy for the Pi. The Pi runs the torch-free path
# (onnx_backend.py, selected automatically by inference_backend.py), so it
# needs ONLY these:

onnxruntime>=1.17          # pure-CPU inference (no GPU build on Pi)
opencv-python>=4.8.0       # camera capture + preprocessing (or opencv-python-headless if no display)
numpy>=1.24.0
flask>=3.1.0               # phone web UI
Pillow>=10.0.0             # OLED rendering
PyYAML>=6.0

# Physical rig I/O (apt is more reliable than pip for these on Pi OS):
#   sudo apt install python3-gpiozero python3-luma.oled
# or, in a venv:
gpiozero>=2.0
luma.oled>=3.12

# NOT installed on the Pi (and must not be): torch, ultralytics, supervision.
# If any of those import, inference_backend falls back to the PC path and
# pulls torch — verify with:  python -c "import inference_backend as b; print(b.BACKEND)"  -> should print 'onnx'

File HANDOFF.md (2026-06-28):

# Session Hand-off — Blood Bowl Dice Tracker

*Last updated: 2026-06-27 (rig is LIVE and reading dice; this session was
field-readiness + UX polish + connectivity + docs. See "⭐ SESSION
2026-06-27" below for the current state and what's open. The older
"LIVE RIG BRING-UP" section remains for deeper background.)*

---

## ⭐ SESSION 2026-06-27 — CURRENT STATE (read this first)

The rig is operational and reading dice live. This session focused on
field readiness: connectivity, UX, the 7" screen, and documentation.

### Connectivity — THREE ways to reach the rig (all working)

| Path | Use when | Address |
|---|---|---|
| Phone over WiFi/hotspot | normal | `http://dicetracker.local:5000` |
| Surface over **Bluetooth PAN** | no WiFi at venue | `http://192.168.44.1:5000` |
| Phone via **Tailscale** | remote admin/SSH anywhere | `100.72.200.96` |

- **Hotspot:** Pi auto-joins the iPhone hotspot ("Ken's iPhone (2)", saved
  profile). The fix when it won't connect: iPhone **Maximize Compatibility
  ON** (forces 2.4GHz the Pi can see) + `sudo nmcli device wifi rescan`
  (plain rescan errors "not authorized" — needs sudo). On the hotspot the
  Pi's IP is `172.20.10.x`; use `dicetracker.local`, not the home IP.
- **Tailscale** (installed this session): mesh VPN, Pi = `100.72.200.96`,
  tailnet `chapman_thor@yahoo.com`. SSH from the phone via Termius (username
  must be lowercase `sevcav`). iOS allows only ONE VPN at a time — toggle
  Tailscale on / regular VPN off to use it. PC can't reach `100.x` unless
  Tailscale is installed on the PC too.
- **Bluetooth PAN** (other session built it, set up + TESTED this session):
  paired KENS-SURFACE (`68:F7:D8:C4:C1:A6`, trusted). Daily recurring step
  on the Surface: Devices & Printers → right-click *dicetracker* →
  **Connect using → Access point**, then browse `192.168.44.1:5000`. Pi side
  is automatic (bt-nap + dnsmasq services). See `deploy/BLUETOOTH_PAN.md`.

### 7" touchscreen (optional add-on, now in use)

ELECROW/Mediatrix MPI7002 over HDMI, runs at 1920×1080 → desktop UI is
microscopic. **Fix: display scale 2× via labwc autostart** —
`~/.config/labwc/autostart` has `wlr-randr --output HDMI-A-1 --scale 2 &`
(survives reboot). View the app on the Pi at `http://127.0.0.1:5000`
(the `http://` is required — Chromium searches otherwise). cups-browsed
auth-popup nuisance was disabled (`systemctl disable --now cups-browsed`).

### Software changes shipped this session (all pushed)

- **P1 OLED fix** — both OLEDs share RST (GPIO25); building the 2nd ssd1309
  with `gpio_RST=25` reset the 1st, blanking P1. Fix: 2nd device uses
  `gpio_RST=None` (in `hardware.py` AND the test scripts). Root cause of
  "Player 1 OLED not working" — was NOT the wiring.
- **OLED confirmed-state** — after a confirm the OLED shows
  "Last roll CONFIRMED / Player X / watching (roll...)" instead of leaving
  the dice up (was confusing).
- **Phone tap-4-corners re-alignment** — `/align` has a "Re-set corners"
  tool: tap the tray's 4 corners (TL,TR,BR,BL) → Save → rewrites
  `tray_roi.json` (overlay quad + axis-aligned crop). Does NOT perspective-
  warp (model only knows the rectangular crop). Alignment is startup-only;
  once live, `/align` shows a "session running" notice (live read is on the
  Live tab — that's expected, not a bug).
- **Games tab** — pinned editable latest roll at top; Started/Export moved
  to bottom; per-game delete + Clear-all (active game protected); a Player
  Names form; and **Load from Game Sheets** (imports coach/team names from
  the league's TourPlay schedule via the Cloudflare Worker proxy —
  `tourplay.py`, default URL pre-filled + auto-loads, see DEFAULT_SHEET_URL).
- **Showcase doc + BOM** — `docs/BB-Dice-Tracker-Showcase.docx` (styled,
  images embedded; regen with `node docs/build_showcase.js`). DESIGN.md §6
  rewritten to the as-built BOM (Dupont+splitters in; lamps/JST/heat-set
  inserts NOT used; 7" screen optional).
- **Repo hygiene** — wiring PNGs (~23MB) removed from git (bloated Pi
  pulls); `docs/` tracked but meant to be skipped on the Pi via
  sparse-checkout (see `deploy/CHEATSHEET.md`).

### OPEN ITEMS / risks (not yet done)

1. **OVERHEATING — real tournament risk.** The Pi thermally shut down once
   this session (sealed case, sustained inference). Recovered on cooldown,
   but a sealed rig WILL overheat across an all-day event. Needs heatsinks /
   a fan / vents. UNADDRESSED.
2. **Sparse-checkout NOT set up on the Pi** — so `git pull` on the rig still
   drags the ~30MB `docs/` folder. Commands are in `deploy/CHEATSHEET.md`;
   run them on the Pi before the next pull.
3. **Day-mode on startup** — rig came up at color-deviation 8.9 (just over
   the 8.0 IR threshold). Reseat the photoresistor lens cap so it forces IR;
   the camera was also clicking (IR-cut filter oscillating at threshold).
4. **Pi password is in chat transcripts** — change with `passwd` when convenient.

---

## Hand-off prompt

You are picking up the **Blood Bowl Dice Tracker** project at
`C:\Users\chapm\Dice Code`. Before doing anything else:

1. Read `DESIGN.md` — single source of truth (header has current status).
2. Read `SETUP.txt` — original settle→confirm UX intent; still canon.
3. Search knowledge-graph memory for: `BB Dice Tracker Project`,
   `BB Dice Tracker Current State 2026-06-12`,
   `BB Dice Tracker Detection Architecture`, `BB Dice Tracker Hardware`,
   `BB Dice Tracker Lessons Learned`, `BB Dice Tracker Networking`.

**Operating rules (locked — do not relitigate):**

- **Camera alignment is ALWAYS the first step of any camera session.**
  Both `dice_tracker.py` and `eval_harness.py` enforce it at startup.
- **Never trust day-mode frames.** Models are trained on IR only; the
  startup self-check + live HUD warning guard this. Verify, don't assume.
- **Retrain quality bar:** mAP@50 ≥ 92% on held-out validation or the new
  ONNX does not replace production.
- **Correction flow:** 4 buttons only, prevention over correction. No
  keyboard/menu correction UI on the rig — late fixes happen in the
  phone web app's game review.
- **No guessing.** Measure with the eval harness / real data, or say so.

## ⭐ LIVE RIG BRING-UP (2026-06-15) — RESUME HERE

The portable Pi rig is wired and the software is RUNNING ON IT headless.
Dice read live off the camera through the full torch-free stack. We are
in the polish/debug phase of the first real run.

**The Pi:** hostname `dicetracker`, user `sevcav`, **IP 192.168.68.85**
(DHCP — may shift; re-find via router or `ping dicetracker.local`).
SSH: `ssh sevcav@192.168.68.85`.

**Bluetooth fallback for the web UI (no-WiFi venues):** when hotspot/cellular
WiFi is unreliable at a store/tournament, the Surface Pro can reach the phone
web UI over **Bluetooth PAN** instead — same Align/Live/Games pages, zero app
code changes. Pi runs a Bluetooth NAP; the Surface joins as a PAN client and
browses the *fixed* URL `http://192.168.44.1:5000/` (static, so it never moves
like the WiFi DHCP IP). One-time setup + pairing + daily-use steps in
`deploy/BLUETOOTH_PAN.md` (configs: `deploy/pan0.sh`, `deploy/dnsmasq-pan.conf`,
`deploy/bt-nap.service`).

**Run the rig — ALWAYS these 3 lines in order, every restart.** The
`. .venv/bin/activate` is MANDATORY; without it you get
`ModuleNotFoundError: No module named 'cv2'`. The venv does NOT persist
across `cd` or a new SSH session, so re-activate every time:
```
cd ~/dice-tracker
. .venv/bin/activate
python dice_tracker.py
```
Headless: it prints the web URL, runs the IR self-check, then waits for
phone alignment. **On the phone (same WiFi):** open the rig URL — the nav
bar has **Align / Live / Games** buttons. Tap **Align**, match tray to the
green outline, **Confirm**, then it goes live. **Games** = the BB3 record
(per-die counts + per-roll fix dropdown).

**To deploy a code change:** PC commits+pushes → on Pi: stop the tracker,
`git pull`, restart, re-align. (Pi pulls from github.com/Sevcav/dice-tracker.)

**To STOP the running tracker:** Ctrl-C (now reliable — installs a SIGINT
handler; prints `[stopping] Ctrl-C received`). If it ever hangs, the
always-works backup is a **second SSH session** → `pkill -f dice_tracker.py`.

**Verified working LIVE on the real Pi:** torch-free backend (`backend OK:
onnx`, 27 classes), all 4 buttons (fire correct names), all 4 LEDs, both
OLEDs (isolation tests `deploy/oled1_test.py`/`oled2_test.py`), USB camera
`/dev/video0`, **live dice reading INCLUDING d16 settling to ONE value.**

**Fixes pushed 2026-06-15 — last few NEED A LIVE CONFIRM on next restart:**
1. **d16 settle** ✅ CONFIRMED LIVE — now settles + shows ONE top value.
   (Was gating on flickering glyph-box count; now gates on DICE/cluster
   count + ≥2 stable faces. `DICE_DEBUG=1` prints `[d16-dbg]` lines if it
   ever won't settle again.)
2. **d16 single value** ✅ — settle display + logged roll + `/games` tally
   show ONE deduced top value per die, not 3 glyph faces. (Recognition was
   always right — rolled 1 → faces {8,2,1} is the correct ring triple.)
3. **Settle speed — FPS-ADAPTIVE (pending live confirm).** Settle felt
   ~2s on the Pi because `COUNT_STABLE_FRAMES=10` is a FRAME count and the
   Pi runs ~5fps vs PC ~30fps. Startup now measures real capture fps and
   sets `settle_frames = max(4, round(SETTLE_SECONDS * fps))`; **tune feel
   via `SETTLE_SECONDS` (=0.5) at top of `dice_tracker.py`.** Startup
   prints `Capture ~X fps -> settle needs N frames` — READ THAT BACK. If
   it settles while a die still wobbles, raise SETTLE_SECONDS to 0.6–0.7.
4. **Ctrl-C stop (pending live confirm)** — SIGINT handler; see "To STOP"
   above.
5. **LED dimming (pending confirm)** — `hardware.py` `LED_BRIGHTNESS=0.2`
   (PWMLED). Edit 0.1–0.35 to taste.

**Open items (after the above):** OLED physical-swap check (which screen
faces which player — both show identical content, doesn't block); case
wire-bulge (cage needs a relief cut or reprint to close — wiring is
heavier than designed); a full ~25-roll live d16 + d6 eval once settle is
solid; the ELECROW 7" touchscreen accessory (standalone, kiosk the web app
at localhost:5000 — DESIGN.md §8, post-bring-up).

**Deploy gotchas seen (so next session doesn't relearn):** `training/
models/` is gitignored so `git pull` won't create it — `mkdir -p` then
`scp combined.onnx` + `combined.onnx.json` from the PC. A stale Pi local
edit may block `git pull` (`git checkout -- <file>` to clear). `setup_pi.sh`
fixed for Trixie (libatlas→libopenblas0). Windows-committed `.sh` may need
`sed -i 's/\r$//'`.

---

**Prior milestone — synthetic-data work stream (2026-06-13):** the tray-crop retrain SHIPPED and the
d16 full-rotation iteration is LIVE-VALIDATED. Production `combined.onnx`
is the full-rotation crop-trained 27-class YOLOv11n (synthetic copy-paste
pipeline in `training/synth_dice.py` et al., full story in
`training/SYNTH_RETRAIN_PLAN.md` STATUS section). Inference crops to the
tray ROI via the `combined.onnx.json` sidecar (pad 8 / pad_bottom 40 —
bottom-wall dice project below the ROI rect). LIVE eval results
(eval_sessions/): **block 66/66 = 100% per-die, pow 18/18** (was 83–90% /
60% pow); **d16 22/26 = 85% value accuracy** (was 12% baseline → 65%
first crop → 85% full-rotation), 0 count-mismatch. d16 eval scores the
ROLLED VALUE via the verified adjacency layer (`d16_geometry.py`, two
consecutive rings 1-8/9-16, deduction + impossible-read warnings live).
Uncertainty thresholds are per-type (`CONF_UNCERTAIN`: block/d6 0.60,
d16 0.80 — crop model confidences run lower than the old model). Backups:
`models/combined_crop_v1_20260612.onnx` (first crop model),
`models/combined_fullframe_backup_20260611.onnx` (pre-crop).

**d16 remaining error mode (know this before iterating):** all live d16
misses are now OFF-BY-ONE RING NEIGHBORS (12→11, 14→13, 1→2) — the model
lands one rotational step from the true top, not wildly wrong. Confidence
is flat (correct 0.82 vs wrong 0.82), so the 0.80 "?" marker won't catch
them and the geometry can't either (an off-by-one neighbor is a legal
face). The weak point is top-vs-side disambiguation, not glyph
recognition. Mitigation in play: nudge-to-re-read; 85% is table-usable.

**Next priorities, in order:**

1. **d16 full-rotation retrain — DONE + LIVE-VALIDATED 2026-06-13.**
   `ROT_D16_MAX=180`, passed val gates (block 93.6 / d6 99.2 / d16 92.7)
   and live eval (85%, see Current state). Deployed. Needed a sliver-box
   fix in `write_yolo_boxes` (a 0px-tall glyph crashed Ultralytics
   augmentation on Windows; `training/_scan_labels.py` finds them).
2. **d6 perspective-tilt retrain — DONE + LIVE-CONFIRMED 2026-06-13.**
   First d6 eval was 89% (both misses 4pip-as-neighbor from tilted dice
   the flat captures never showed). Added perspective-TILT augmentation
   to `synth_dice.py` (block/d6 only; `P_TILT`/`TILT_FRAC`), retrained,
   deployed. Re-eval: **40/40 = 100% over 22 rolls, 4pip 6/6** (was 1/3),
   tilted rolls included. The tilt-augmented model is production
   `combined.onnx`; prior full-rotation model kept as
   `models/combined_crop_fullrot_20260613.onnx`. The synthetic-data work
   stream is COMPLETE — live scoreboard: block 100%, d6 100%, d16 85%,
   pow 60%→100%, zero new dice captured.
3. **GPIO + OLED + Pi port — CODE DONE 2026-06-14, NOW LIVE ON THE PI
   (2026-06-15, see top "LIVE RIG BRING-UP" section — this is the active
   work).** Built:
   - `onnx_backend.py` — torch-free inference (custom YOLOv11 decode,
     agnostic NMS, IoU tracker + smoother). Bit-for-bit parity with the
     ultralytics path on banked frames; full Pi pipeline (detect→track→
     smooth→d16 geometry) verified via `DICE_BACKEND=onnx`.
   - `inference_backend.py` — auto-selects ultralytics (PC) vs onnx (Pi);
     `dice_tracker`/`eval_harness` refactored onto it, PC path unchanged.
   - `hardware.py` — buttons (17/27/22/23) + LEDs (5/6/13/19) + dual
     SSD1309 (SPI0 CE0/CE1) against the DESIGN.md locked map; no-op stub
     off-Pi. Wired into the loop: a player's confirm button = set active
     + confirm (one press); OLEDs mirror the live read.
   - `requirements-pi.txt`, `deploy/setup_pi.sh`,
     `deploy/dice-tracker.service`, `deploy/README.md`.
   - **HEADLESS (the design — sealed box, phone is the only screen):** on
     the Pi dice_tracker runs with NO cv2 window automatically (no
     `$DISPLAY` / onnx backend; `--gui` forces preview, `--headless`
     forces off). Alignment is phone-driven — `webapp` `/align` streams
     the live feed + green tray outline (MJPEG), operator taps Confirm
     (`alignment_check_web`). Reject/Undo/Confirm available from the phone
     (`/api/action`) and the GPIO buttons; both share the synthetic-key
     dispatch. Day-mode prompt auto-proceeds headless (flag stays live).
   First bring-up: follow `deploy/README.md` (git pull → setup_pi.sh →
   scp model → `python dice_tracker.py` → align on phone).
5. When convenient: relabel the 6 bad d16 frames in Roboflow
   (`training/crop_common.py` EXCLUDE_STEMS) + the manual queue
   (`training/datasets/auto_labeled/manual_queue.txt`).

**Gotchas that will bite you** (full list in DESIGN.md §9 + memory):
OpenCV window titles/HUD must be ASCII-only on Windows; `input()` freezes
cv2 windows (use `pumped_input` in eval_harness); supervision must stay
<0.30 until ByteTrack migration; Ultralytics on Windows needs
`workers=0`; lower NMS IoU keeps MORE boxes; DHCP moves IPs — trust
`lan_ip()` printed at startup, not yesterday's address.

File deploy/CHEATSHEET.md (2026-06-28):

# Rig cheat sheet

Quick copy-paste commands. The stuff I always forget.

## Keep docs/ off the Pi (sparse-checkout — one-time setup)

The repo holds a `docs/` folder (showcase document + images, ~15 MB) that
the Pi does NOT need. Configure the Pi's clone to pull code only, skipping
`docs/`, so pulls stay small. Run ONCE on the Pi:

```bash
cd ~/dice-tracker
git sparse-checkout init --cone
git sparse-checkout set '/*'          # everything at the repo root...
git sparse-checkout add '!/docs'      # ...except docs/  (cone mode excludes it)
git read-tree -mu HEAD                 # apply: drops docs/ from the working tree
```

If the above cone syntax gives trouble on an older git, use non-cone mode:

```bash
cd ~/dice-tracker
git sparse-checkout init --no-cone
printf '/*\n!/docs/\n' > .git/info/sparse-checkout
git read-tree -mu HEAD
```

Verify: `ls ~/dice-tracker` should show NO `docs/` folder. Normal
`git pull` from then on skips docs/ automatically.

## SSH into the rig (from the PC)

```bash
ssh sevcav@dicetracker.local
```

User `sevcav` (LOWERCASE — capitalized fails). mDNS hostname
`dicetracker.local`. Prompts for the Pi password. If `dicetracker.local`
won't resolve (network blocks mDNS), use the LAN IP:

```bash
ssh sevcav@<pi-ip-address>
```

PowerShell note: if `ssh` is "not recognized", call it by full path:
`& "C:\WINDOWS\System32\OpenSSH\ssh.exe" sevcav@dicetracker.local`
(a fresh PowerShell window usually fixes the PATH).

## Reach the rig — three ways

| From | When | Address |
|---|---|---|
| Phone/PC on same WiFi or hotspot | normal | `http://dicetracker.local:5000` |
| Surface over Bluetooth (no WiFi) | dead venue WiFi | `http://192.168.44.1:5000` |
| Phone via Tailscale (remote) | from anywhere | `100.72.200.96` (SSH) |

- **Tailscale** (remote SSH from the phone): Pi is `100.72.200.96` on the
  tailnet. Phone needs the Tailscale app ON (only one VPN at a time on iOS —
  toggle your regular VPN off). SSH via Termius, username lowercase `sevcav`.
  The PC can't use `100.x` unless Tailscale is installed on the PC too.
- **Bluetooth PAN** (Surface, no WiFi): on the Surface, Devices & Printers →
  right-click *dicetracker* → Connect using → Access point, then browse
  `192.168.44.1:5000`. Full setup in `deploy/BLUETOOTH_PAN.md`.
- **iPhone hotspot won't connect?** Turn ON **Maximize Compatibility**
  (Settings → Personal Hotspot) so it broadcasts 2.4GHz the Pi can see, then
  `sudo nmcli device wifi rescan` (needs sudo, or it errors "not authorized").

## 7" screen too small

Runs at 1920×1080 → tiny UI. Scale 2× (already set to persist via
`~/.config/labwc/autostart`). To change live:
```bash
wlr-randr --output HDMI-A-1 --scale 2     # 1.5 / 2 / 2.5 to taste
```
View the app on the Pi at `http://127.0.0.1:5000` (the `http://` is required).

## Activate the venv (BEFORE running anything by hand)

It's `.venv`, NOT `venv`. luma/gpiozero/onnxruntime live here.

```bash
source .venv/bin/activate
```

Prompt shows `(.venv)` when it's active — if you see that, it's already on,
skip this.

## Run the tracker by hand (dev / debugging)

```bash
cd ~/dice-tracker
git pull
source .venv/bin/activate
python dice_tracker.py
```

## Run with NO PC (store mode) — autostart at boot

Install ONCE (needs SSH this one time):

```bash
sudo cp deploy/dice-tracker.service /etc/systemd/system/
sudo systemctl enable --now dice-tracker
```

After that, every power-on starts the tracker automatically. At the store:
just plug in, wait ~30-60s, then use the phone — no terminal needed.

- Phone alignment: `http://dicetracker.local:5000/align`  (always step one)
- Phone live view + controls: `http://dicetracker.local:5000/`

### systemd controls (when SSH'd in)

```bash
systemctl status dice-tracker      # is it running?
sudo systemctl restart dice-tracker
sudo systemctl stop dice-tracker   # stop it (e.g. to run by hand)
journalctl -u dice-tracker -f      # watch live logs
```

## Phone workflows (no PC)

Three tabs: **Align**, **Live**, **Games**. Hard-refresh after a service
restart (phones cache the page).

### Align (startup only)

Alignment runs ONCE at startup, before the live session. The Align tab
shows the camera + green tray outline only during that step; once a
session is live it shows a "session running" notice (the live image is on
the **Live** tab — that's expected, not a bug).

- Adjust the arm so the tray matches the green outline -> **Confirm**.
- Camera moved (e.g. new case)? Tap **Re-set corners**, then tap the
  tray's 4 corners in order **top-left, top-right, bottom-right,
  bottom-left** -> **Save corners** -> **Confirm**. This rewrites
  `tray_roi.json` (overlay quad + the axis-aligned crop the model uses).
  It does NOT dewarp the image — re-square the camera for best accuracy.
- To re-align mid-session: `sudo systemctl restart dice-tracker`, then
  re-do alignment before confirming.

### IR mode (must be IR — always)

Models are trained on IR (monochrome) frames. The rig forces IR via the
photoresistor lens cap / light shield.

- **Day-mode warning ON = a real problem** (shield not sealing / too
  bright). No warning = IR = good.
- Check on the **Live** tab (monochrome = IR) or in the logs:
  `journalctl -u dice-tracker -f` -> `[ok] camera back in IR mode` /
  `[WARNING] camera flipped to DAY mode`.
- The first few frames after camera plug-in are always day-mode color
  while it drops into IR — ignore the startup blip.

### Games (clear test data)

- **Games** tab -> per-game **delete** (removes the game + its rolls), or
  **Clear all games** at the top to wipe everything.
- The game currently being recorded shows **active** instead of delete and
  is protected from both delete and Clear all.
- Clear out bring-up/test games here before a real tournament.

## OLED tests (deploy/)

```bash
python deploy/oled1_test.py       # only CE0/pin24 (P1, left)
python deploy/oled2_test.py       # only CE1/pin26 (P2, right)
python deploy/oled_both_test.py   # BOTH at once, distinct text per screen
python hardware.py                # prints GPIO/OLED availability + pin map
```

## Quick gotchas

- Model `combined.onnx` is gitignored — must already be at
  `~/dice-tracker/training/models/`. If the service crash-loops, check this
  first: `ls ~/dice-tracker/training/models/combined.onnx`
- OLEDs share RST (GPIO25). Only the FIRST ssd1309 device may drive RST;
  the second uses `gpio_RST=None` or it blanks the first panel.
- Backend must be onnx on the Pi:
  `python -c "import inference_backend as b; print(b.BACKEND)"` → `onnx`

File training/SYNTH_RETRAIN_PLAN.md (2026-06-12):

# Hand-off: Synthetic training data + POW/D16 fix

*Work-stream hand-off, written 2026-06-12. For general project context
read `HANDOFF.md` and `DESIGN.md` first, and search memory for the
`BB Dice Tracker` entities. This file scopes ONE work stream.*

## Mission

Eliminate manual capture-and-label work by generating training data from
real pixels (copy-paste compositing), retrain the combined 27-class model
tray-cropped, and fix the two measured weaknesses: **POW recall (~60%)**
and **D16** (never live-evaluated; 88.5% val mAP). Implement the D16
adjacency-deduction layer.

## Evidence already established — do not re-derive

- **pow failures are a RESOLUTION problem.** Re-running misread frames
  cropped to the tray ROI (~2x die pixels) correctly identified pow in
  4/10 misread rolls. Frames + ground truth:
  `retrain_candidates/block/eval_miss_*.{jpg,json}`; session reports:
  `eval_sessions/eval_block_20260611_*.json`.
- **Naive crop inference with the current full-frame-trained model breaks
  other classes** — the crop must be trained in, not bolted on.
- Camera is near-overhead: a block/d6 die crop rotated to ANY angle and
  pasted at ANY tray position is physically valid.
- **D16 dice must be composited as WHOLE units** — they are labeled 3
  boxes per die (top + 2 visible sides) and the faces are geometrically
  married. Modest rotations only.
- Combined 27-class model is production (`training/models/combined.onnx`,
  block 92.4 / d6 98.4 / d16 87.4 mAP@50). Datasets:
  `training/datasets/{block,d6,d16}`, merge logic in
  `training/merge_datasets.py` (block ids 0-4, d6 5-10, d16 11-26).
- `tray_roi.json` is saved in 1920x1080 coordinates; frames are 1280x720
  — scale by width ratio (see `color_deviation`/`alignment_check` usage
  in `dice_tracker.py`).

## Deliverables, in order

1. **`training/auto_label_rejects.py`** — convert banked
   `retrain_candidates/*` frames into YOLO labels. The reject/miss JSONs
   carry predicted boxes + (for eval misses) ground-truth labels; for
   non-count-mismatch rolls, boxes sorted left-to-right pair with the
   truth list in order. Skip count-mismatch frames (boxes incomplete) or
   queue them for manual labeling.
2. **`training/synth_dice.py`** — the compositor:
   - harvest labeled die crops from the existing datasets
   - build clean tray backgrounds by inpainting dice out of real frames
     (`cv2.inpaint` with label boxes as mask)
   - paste crops: random rotation (any angle for block/d6; whole-die,
     small-angle for d16), random position incl. wall/corner bias,
     brightness matched to the local background (vignette)
   - weight generation toward pow faces and wall positions
   - emit YOLO labels; build everything **tray-cropped**
3. **Retrain** combined YOLOv11n on real + auto-labeled + synthetic,
   tray-cropped. Recipe (`training/train_all.py`): imgsz=640, batch=16,
   epochs=100, patience=20, device=0, **workers=0 (Windows hard
   requirement)**.
4. **Quality bar (locked):** per-type mean mAP@50 >= 92% on held-out
   validation or the new ONNX does not replace production. Keep the
   current `combined.onnx` until then.
5. **Inference must match training:** when deploying the crop-trained
   model, `dice_tracker.py` and `eval_harness.py` must crop frames to the
   tray ROI before `predict`.
6. **D16 adjacency layer** (new module or `dice_types.py`): lookup
   `(side_A, side_B) -> top`; opposite faces sum to 17; both of the
   user's D16s share one adjacency map (same manufacturer, one white one
   black). Derive the table from the physical dice — **verify with the
   user, do not assume a standard layout**. Use it to (a) deduce the top
   face when top confidence is low, (b) flag geometrically impossible
   face triples as misreads before the player confirms.
7. **Validation at the rig (user time, ~25 rolls per type):**
   - d16 FIRST with the CURRENT model — there is no live d16 baseline
   - then block + d16 with the new model:
     `python eval_harness.py --type block --model <new>`
   - compare against `eval_sessions/` baselines (block per-die 82.6-89.6%).

## Rules

- Camera alignment is always the first step of a live session (built in).
- Train only on IR frames (color deviation < 6; helper in dice_tracker).
- No guessing — every accuracy claim comes from the eval harness.

---

## STATUS — updated 2026-06-12 (build session)

Built and QC'd (all in `training/` unless noted):

- `crop_common.py` — shared geometry. Key verified facts: the Roboflow
  640x640 exports are a PURE CENTER CROP of the raw 1280x720 frames
  (`export = raw[40:680, 320:960]`); labels are SYMBOL-REGION POLYGONS
  (block symbol ring / d6 pip cluster / d16 number glyphs), not die
  boxes; d6+d16 exports carry augmented copies — only pixel-verified
  originals are used (`synth_assets/originals_index.json`).
  Per-session tray drift found (May 5 sessions ~33px low, May 6 worse):
  `session_alignments()` warps every session into the calibrated
  tray_roi space (ECC on median backgrounds, dual-seeded).
- `auto_label_rejects.py` (deliverable 1) — 17 frames auto-labeled,
  26 queued in `datasets/auto_labeled/manual_queue.txt`.
- `synth_dice.py` (deliverable 2) — backgrounds are per-session MEDIAN
  stacks (no inpainting needed — fixed camera makes the median a clean
  empty tray); die cutouts via background subtraction + convex hull;
  pow weighted 3x, wall band 50%/corner 30%, no flips (symbols are
  chiral); d16 pasted as whole dice carrying 3 glyph labels.
- `build_crop_dataset.py` — `datasets/combined_crop`: 386 real +
  17 auto + 2150 synth train / 112 real valid / 56 real test.
  Valid/test are REAL ONLY. IR threshold used is 8.0 in-tray (the
  production DAY_MODE_DEVIATION) — the plan's "< 6" predates the
  in-tray recalibration and would discard the whole d6 session
  (median 7.2, not day mode).
- `val_per_type.py` — per-type mean mAP@50 vs the 92% bar.
- Deliverable 5 (crop-matched inference) — `models/<stem>.onnx.json`
  sidecar (`{"tray_crop": true}`, written by train_all.py);
  `dice_tracker.predict_detections()` crops to the tray ROI and shifts
  boxes back to full-frame coords; eval_harness uses the same helper
  (`--model combined_crop`). Sidecar-less models run full-frame as
  before; production `combined.onnx` untouched.
- Deliverable 6 (D16 adjacency) — `derive_d16_adjacency.py` mined the
  table from 458 labeled dice (16/16 pairs, 24-33 votes, no conflicts):
  TWO RINGS in consecutive order (1..8, 9..16), top N flanked by ring
  neighbors N±1; opposite faces sum to 17 across rings. Implemented in
  `d16_geometry.py` (project root) + dice_tracker integration:
  impossible-read warnings active; top-face deduction is GATED by
  `ADJACENCY_VERIFIED = False` until physically verified (procedure in
  the module footer). BONUS: the mining exposed ~7 mislabeled glyphs in
  6 frames (geometrically impossible triples) — excluded via
  `crop_common.EXCLUDE_STEMS`; relabel them in Roboflow when convenient.

**TRAINED + BAR PASSED (2026-06-12).** `models/combined_crop.onnx`
(+ `.onnx.json` sidecar), early-stopped ~epoch 53. Per-type mean mAP@50
vs the full-frame combined baseline:

| type  | crop VAL | crop TEST | full-frame baseline |
|---|---|---|---|
| block | 94.1% | 99.5% | 92.4% |
| d6 | 98.4% | 99.5% | 98.4% |
| d16 | 92.7% | 94.1% | 87.4% |

(Weak-looking val classes — pow 0.876, D16_8 0.713 — are ~0.99 on the
test split: small-sample noise, ~14 val instances per class.)

Remaining (user, in order):
1. ~~Verify the D16 table against the physical dice~~ DONE 2026-06-12 —
   user confirmed by rolled spot-checks; `ADJACENCY_VERIFIED = True`,
   deduction layer fully active.
2. At rig: d16 baseline eval with the CURRENT model first
   (`python eval_harness.py --type d16 --model combined`), then block +
   d16 with the new model (`--model combined_crop`), ~25 rolls each.
3. Deploy only if the live eval beats the baselines (block per-die
   82.6-89.6%, pow recall ~60%): copy combined_crop.onnx over
   models/combined.onnx AND combined_crop.onnx.json over
   combined.onnx.json.
4. When convenient: relabel the 6 bad d16 frames in Roboflow
   (`crop_common.EXCLUDE_STEMS`) and clear the manual queue
   (`datasets/auto_labeled/manual_queue.txt`).

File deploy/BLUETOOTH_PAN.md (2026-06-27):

# Bluetooth access to the web UI (Surface Pro, no WiFi)

At the store the hotspot/cellular WiFi is unreliable, which breaks the phone
web UI even though the Pi's dice **detection** works fine. This sets up a
**Bluetooth PAN** (Personal Area Network) so the **Surface Pro does exactly what
the phone does over WiFi** — same Align / Live / Games pages, same controls —
just over Bluetooth instead.

**No application code changes.** The Pi runs a Bluetooth NAP (Network Access
Point); the Surface joins as a PAN client. That brings up a normal TCP/IP link
over Bluetooth, so the browser just opens `http://192.168.44.1:5000/` and hits
the *identical* Flask app. The phone-over-WiFi path is untouched and still works
whenever WiFi is available.

```
 Pi (dicetracker)                         Surface Pro (Windows 11)
 ┌───────────────────────────┐           ┌──────────────────────────┐
 │ dice_tracker.py + Flask   │           │ Edge/Chrome browser      │
 │   :5000  (0.0.0.0)        │           │  http://192.168.44.1:5000│
 │ bt-nap.service (NAP)──────┼─Bluetooth─┼──PAN client (Access pt.) │
 │ pan0 bridge 192.168.44.1  │   PAN     │  gets 192.168.44.x (DHCP)│
 │ dnsmasq (DHCP on pan0)    │           │                          │
 └───────────────────────────┘           └──────────────────────────┘
```

The static `192.168.44.1` also kills the "DHCP moves the Pi's IP" gotcha from
HANDOFF — the Bluetooth URL never changes.

---

## One-time Pi setup

Run on the Pi from the repo root (`~/dice-tracker`). All steps are idempotent.

```bash
# 1. Packages: NAP server (bluez-tools), bridge tooling, DHCP.
sudo apt-get update
sudo apt-get install -y bluez-tools bridge-utils dnsmasq

# 2. DHCP for the PAN link.
sudo cp deploy/dnsmasq-pan.conf /etc/dnsmasq.d/pan.conf
sudo systemctl enable --now dnsmasq
sudo systemctl restart dnsmasq

# 3. NAP + bridge service (brings up pan0, then runs bt-network).
chmod +x deploy/pan0.sh
sudo cp deploy/bt-nap.service /etc/systemd/system/
sudo systemctl daemon-reload
sudo systemctl enable --now bt-nap

# 4. Sanity check.
ip addr show pan0                 # should show inet 192.168.44.1/24
systemctl status bt-nap dnsmasq   # both active
```

> If `dnsmasq` fails to start, another resolver may hold port 53 — this config
> sets `port=0` (DHCP only) to avoid that, so a failure here usually means a
> stale system dnsmasq config; check `journalctl -u dnsmasq`.

> Windows-committed `.sh` files sometimes carry CRLF line endings (see HANDOFF).
> If `pan0.sh` won't run, `sed -i 's/\r$//' deploy/pan0.sh`.

---

## One-time pairing (Pi ⇄ Surface)

On the Pi:

```bash
bluetoothctl
# inside the prompt:
power on
agent on
default-agent
discoverable on
pairable on
# ...now pair from the Surface (next section). When it appears / asks to pair,
# accept. Then trust it so it reconnects automatically:
trust <SURFACE_BT_MAC>
discoverable off       # optional once paired
quit
```

On the **Surface Pro**: Settings → Bluetooth & devices → **Add device** →
Bluetooth → pick **dicetracker** → confirm the pairing code matches the Pi.

---

## One-time Surface setup (Windows 11)

After pairing, tell Windows to use the Pi as a network access point:

1. Settings → Bluetooth & devices → **Devices** → scroll to **More devices and
   printer settings** (opens the classic Devices and Printers panel).
2. Right-click **dicetracker** → **Connect using** → **Access point**.
3. Windows brings up the PAN link and pulls a `192.168.44.x` lease from the Pi.

Verify in a terminal (`ipconfig`): the Bluetooth Network Connection should have
an address like `192.168.44.10`. Then:

```
ping 192.168.44.1
```

Open `http://192.168.44.1:5000/` in the browser and bookmark it.

---

## Daily use at the store

1. Pi powered on, `dice_tracker.py` running (or the `dice-tracker` service).
2. On the Surface: **Connect using → Access point** on the **dicetracker**
   device (step 2 above — this is the only recurring step).
3. Browse to `http://192.168.44.1:5000/`.
   - **Align** → match the tray to the green outline, Confirm.
   - **Live** → live read + dice-type / player buttons.
   - **Games** → the BB3 record + CSV export.

Everything works with WiFi/cellular fully off — that's the point.

---

## Troubleshooting

- **Surface got a 169.254.x.x address** (APIPA, not 192.168.44.x): the DHCP
  lease didn't arrive. On the Pi check `systemctl status dnsmasq`, confirm the
  conf is at `/etc/dnsmasq.d/pan.conf`, and that `bnep0` is enslaved to the
  bridge: `bridge link` (or `brctl show pan0`) should list a `bnep*` interface
  once the Surface connects. Reconnect the Access point from Windows.
- **No `pan0` interface**: `sudo systemctl restart bt-nap`, then
  `ip addr show pan0`. Check `journalctl -u bt-nap` — a missing `bt-network`
  means `bluez-tools` didn't install.
- **Can't reach :5000 but ping works**: the tracker isn't running, or it bound
  elsewhere — confirm `dice_tracker.py`/`webapp.py` is up; it listens on
  `0.0.0.0:5000` so the PAN address is covered.
- **Pairing won't take / won't reconnect**: re-pair, and make sure you ran
  `trust <SURFACE_BT_MAC>` in `bluetoothctl` so the Pi accepts it automatically.
- **Alignment video is sluggish over Bluetooth**: expected ceiling — only the
  alignment MJPEG is bandwidth-heavy (live play is tiny JSON polling). It's a
  brief one-time step; if it's too slow we can add a low-quality stream mode
  used only by the Surface (deferred follow-up).

## Fallback

If Bluetooth ever proves too slow, a **USB tether** (Pi ⇄ Surface USB, RNDIS
gadget) gives a faster wired link to the same `:5000` UI — at the cost of a
cable. Not set up here; noted for completeness.

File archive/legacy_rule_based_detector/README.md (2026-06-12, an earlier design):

# Legacy Rule-Based Detector — Archived

This folder contains the original rule-based dice detection and classification
pipeline. It has been **retired** in favour of a YOLO-based object detector
trained via Roboflow.

## Why this was archived

- Detection relied on detecting a saturated red tray colour. In IR mode
  (the chosen production lighting strategy), the tray loses its red colour
  and `find_tray_roi` returns nothing.
- `_mask_dice` had a polarity bug that flooded the combined mask with white,
  collapsing all dice into a single oversized contour. Empirically validated
  in `debug_detect_pipeline.py` against a real IR frame.
- Filter parameters (`MIN_AREA`, `MAX_AREA`, `EDGE_EXCLUSION_PX`, etc.) were
  tuned for the original camera at the original working distance. The new
  Arducam B0205 at 12 in produces dice at a different pixel scale, requiring
  a re-tune of every threshold.
- Maintaining hand-tuned thresholds for each new lighting condition is the
  failure mode this codebase kept hitting. A trained CNN handles variability
  in lighting / glare / shiny dice in a way no fixed threshold can.

## Replacement architecture

- **Detection + classification:** single YOLOv8n model trained on labelled
  frames. Outputs `(class, x, y, w, h, confidence)` per die in one pass.
- **Labelling:** Roboflow web UI with SAM-assisted auto-suggestion.
- **Training:** Roboflow hosted training (free tier) or local Ultralytics
  if needed.
- **Deployment:** export ONNX → drop into `classifier/` → ONNX Runtime on Pi.
- **Tray ROI:** still calibrated once via clicked-corner script (the
  YOLO model itself can search the full frame, but cropping to the tray
  region speeds inference and reduces false positives outside the tray).

## What's in this archive

| File | Purpose |
|---|---|
| `detect_dice.py` | Mask + contours + watershed split (rule-based) |
| `classify_die_type.py` | Heuristic to guess "block die" vs other types |
| `block_dice_classifier.py` | PyTorch MobileNetV3 classifier wrapper |
| `block_dice_classifier_onnx.py` | ONNX Runtime classifier wrapper |
| `export_onnx.py` | PyTorch → ONNX export script |
| `prepare_training_data.py` | Train/val split + augmentation script |
| `train_block_dice.py` | PyTorch training loop |
| `label_live_dice.py` | Live-feed per-die labelling tool |
| `debug_detect_pipeline.py` | Stage-by-stage detector debug dump |
| `debug_detection.py`, `debug_settle.py`, `debug_stability.py` | Various detector debug scripts |
| `test_tray.py`, `test_watershed.py` | Detector unit tests |
| `main.py` | Top-level loop wiring detector + classifier + UI |
| `reading/` | Higher-level "read this die" wrappers |
| `calibrate_tray_roi.py` | Tray-corner calibration tool (still useful — may be revived under YOLO) |
| `tray_roi.json` | Saved 4-corner tray calibration |

## Recovery

If the YOLO approach fails or proves unsuitable, individual files can be
moved back to their original locations. Nothing here was deleted — only
relocated.

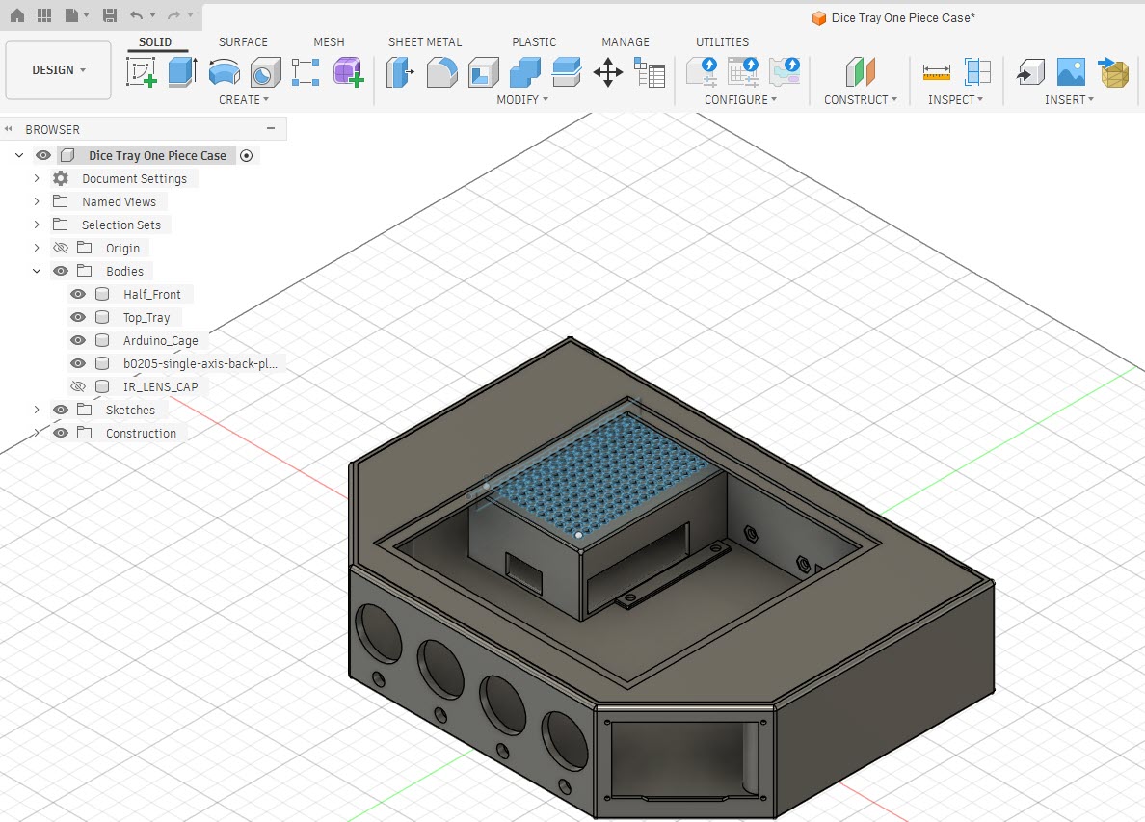
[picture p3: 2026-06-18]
docs/Fusion of Dice Tracker.jpg

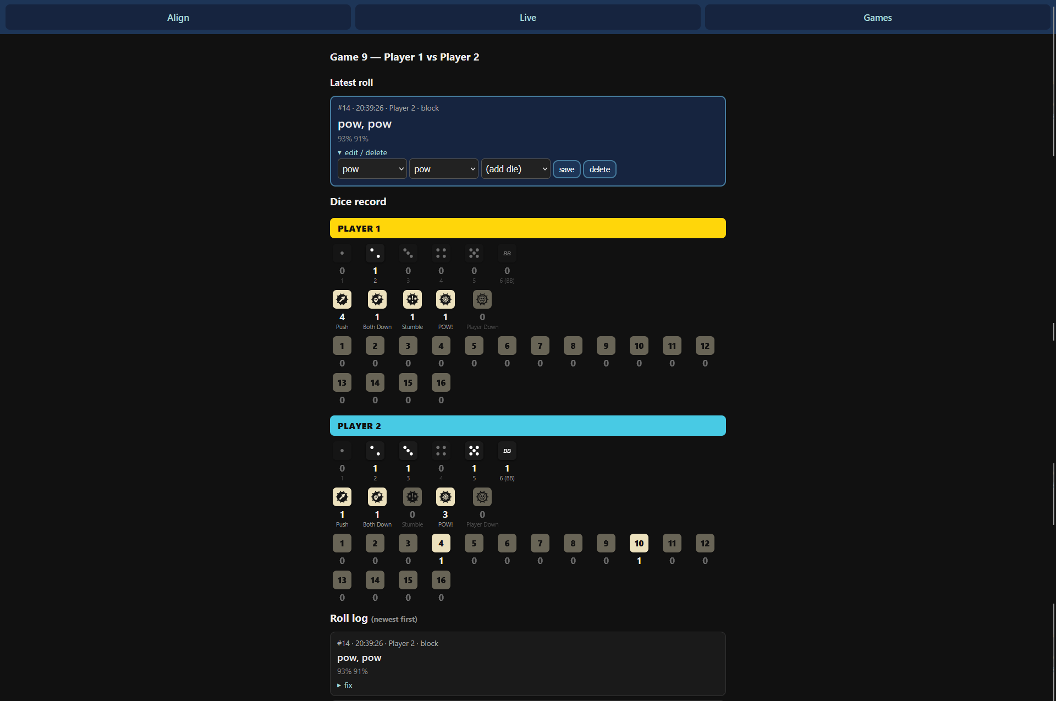
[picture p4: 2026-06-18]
docs/Games Page.png

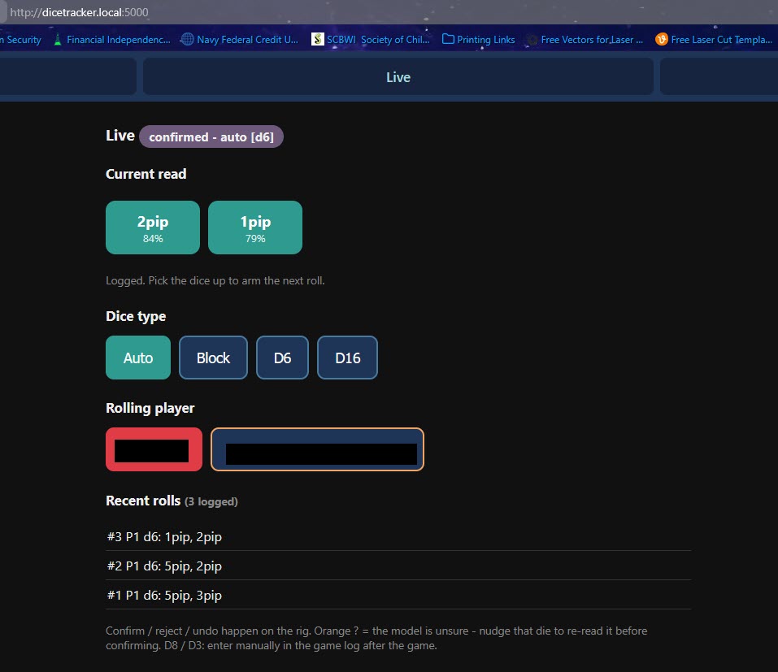
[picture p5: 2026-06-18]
docs/Live Tracker.jpg

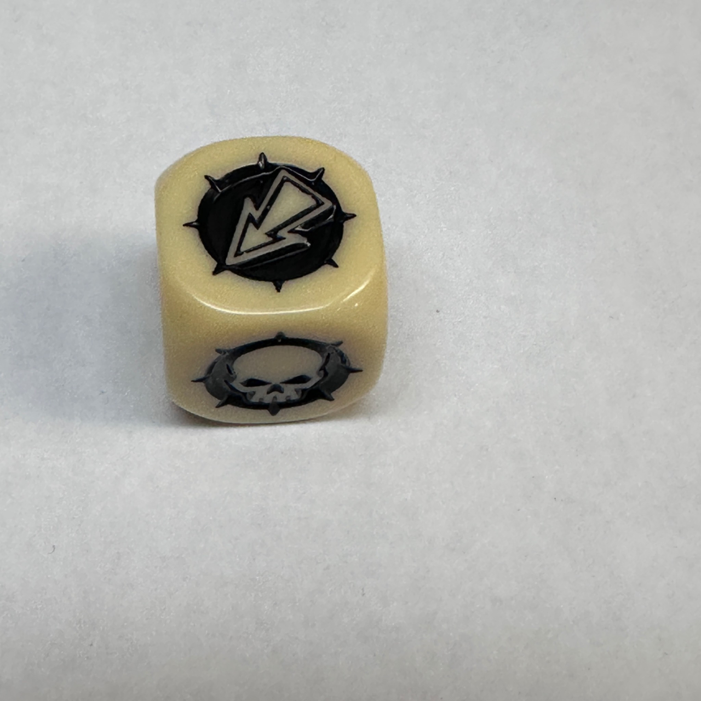
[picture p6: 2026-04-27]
Dice Images/Push Angle 3.jpg

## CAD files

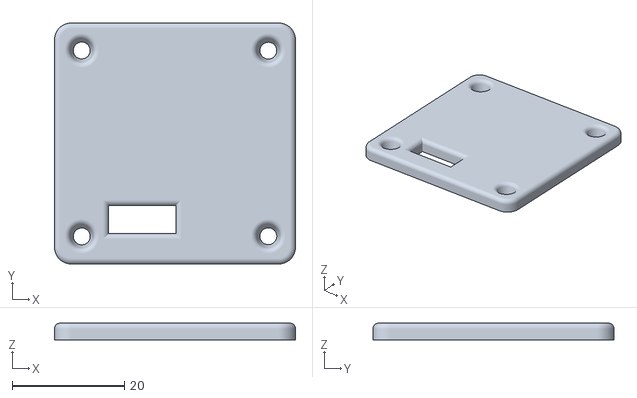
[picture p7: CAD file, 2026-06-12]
Stls/Arducam+1080p+Day+Night+USB+Camera+Case/baby-camera-rear-j-kat-3-negative.stl
43.0 x 43.0 x 3.00

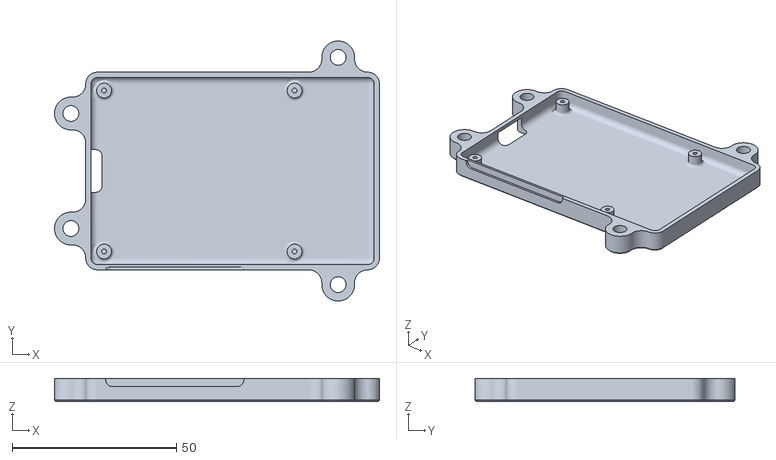
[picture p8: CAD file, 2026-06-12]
Stls/Bottom_Case.STL
99.0 x 79.2 x 7.10

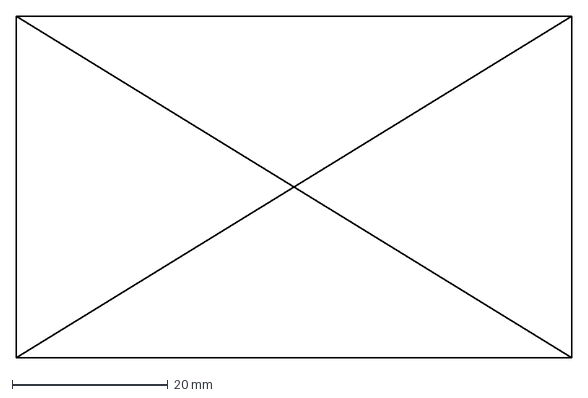
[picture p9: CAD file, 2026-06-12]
Stls/Sketch12_Left.dxf
71.3 x 43.8 mm

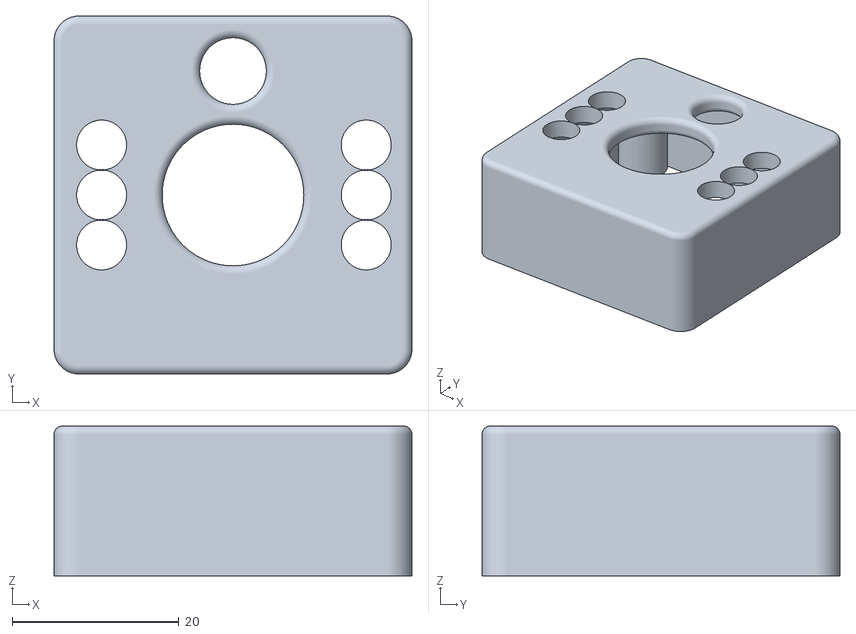
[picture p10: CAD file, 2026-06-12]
Stls/Arducam+1080p+Day+Night+USB+Camera+Case/baby-camera-front-fillet.stl
43.0 x 43.0 x 18.0

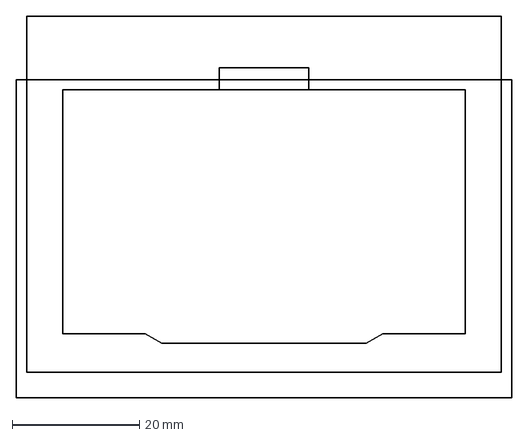
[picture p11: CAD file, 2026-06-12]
Stls/OLED_Window.dxf
77.8 x 60.0 mm

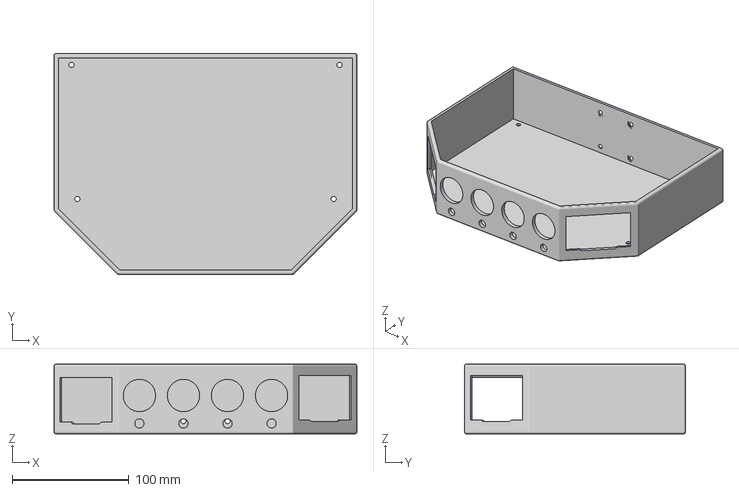
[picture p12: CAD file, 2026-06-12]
Stls/Dice Tray Bottom.3mf
260.0 x 190.0 x 60.0 mm

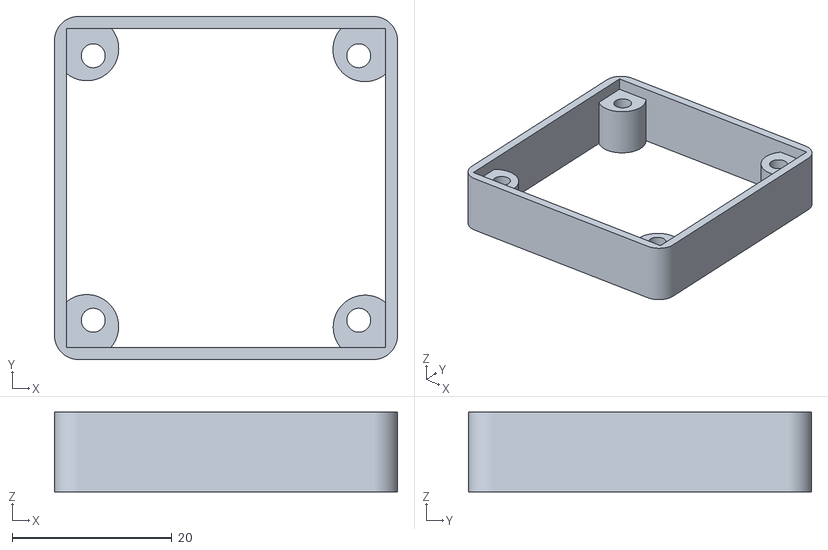
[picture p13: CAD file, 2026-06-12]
Stls/Arducam+1080p+Day+Night+USB+Camera+Case/baby-camera-middle-fillet.stl
43.0 x 43.0 x 10.0

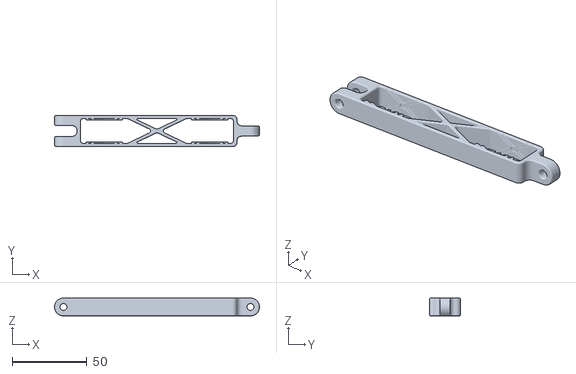
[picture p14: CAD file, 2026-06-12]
Stls/Camera_Link.STL
137.0 x 21.0 x 12.0

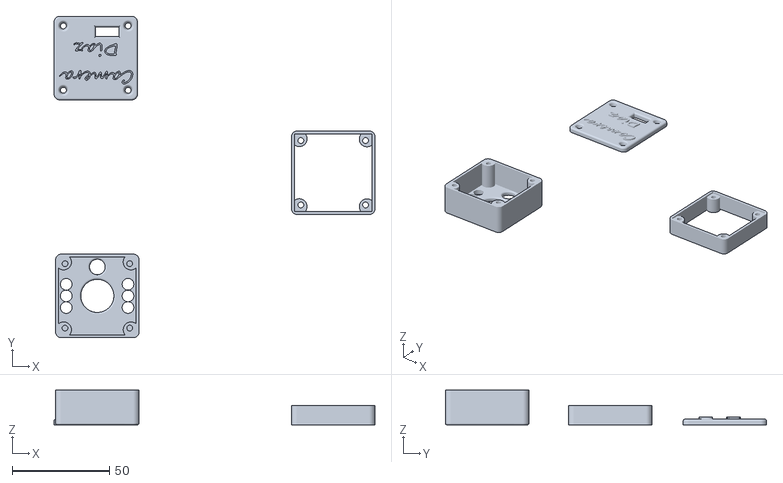
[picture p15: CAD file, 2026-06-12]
Stls/Arducam+1080p+Day+Night+USB+Camera+Case/baby-camera-front-fillet-logo.stl
165.2 x 165.4 x 18.0

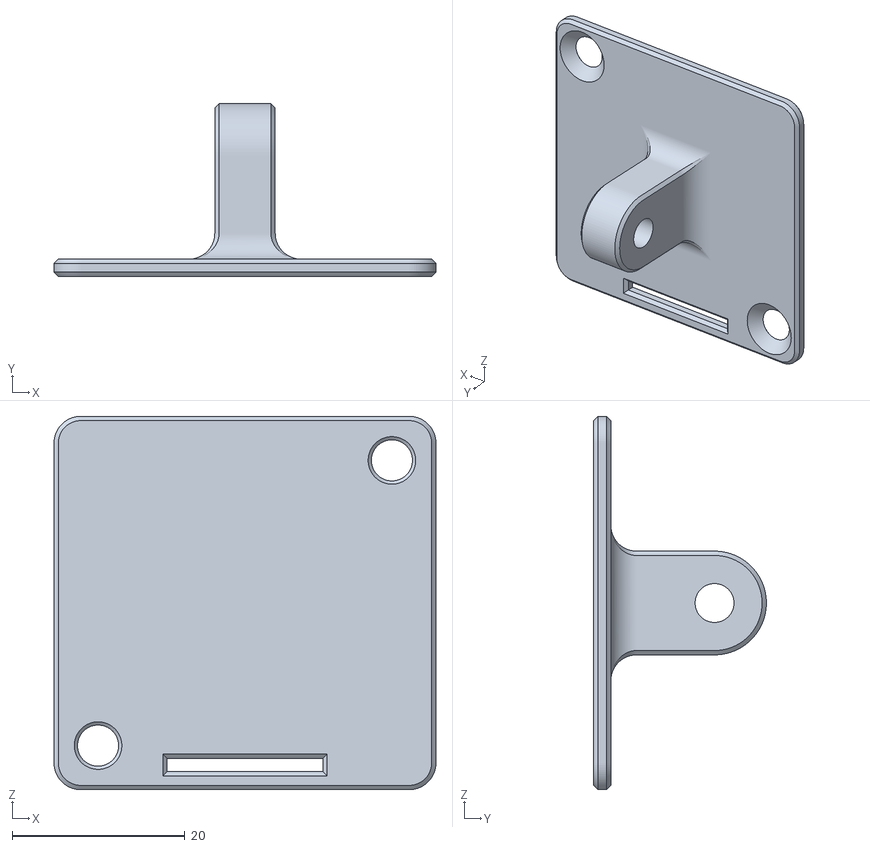
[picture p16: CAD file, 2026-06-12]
Stls/Camera_Mount.STL
44.2 x 20.0 x 43.2

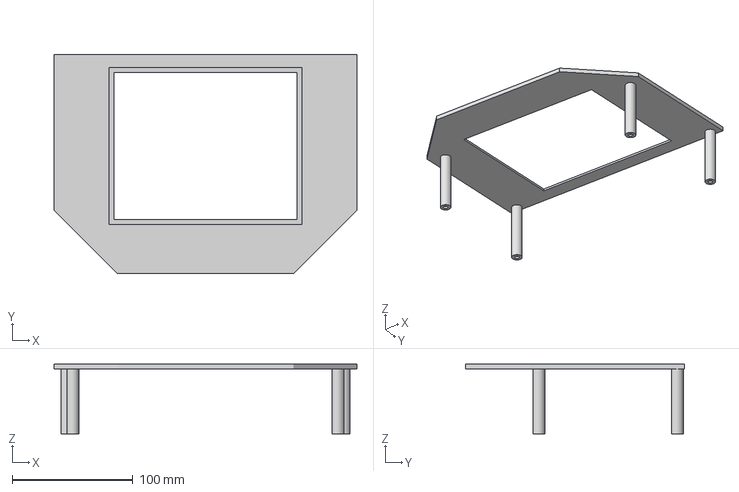
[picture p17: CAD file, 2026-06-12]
Stls/Dice Tray Top.3mf
251.4 x 181.4 x 58.0 mm

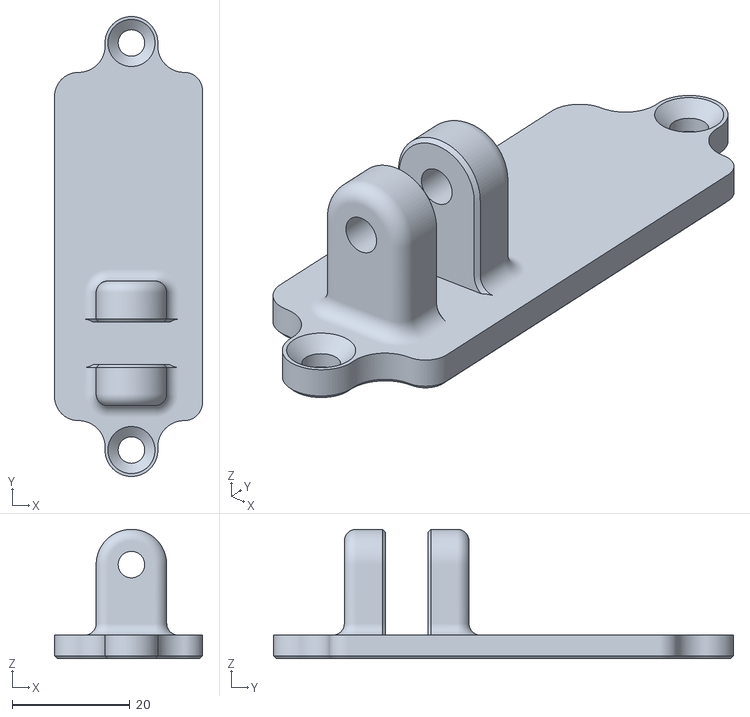
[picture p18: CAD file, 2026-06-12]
Stls/Camera_Base.STL
25.2 x 78.2 x 22.0

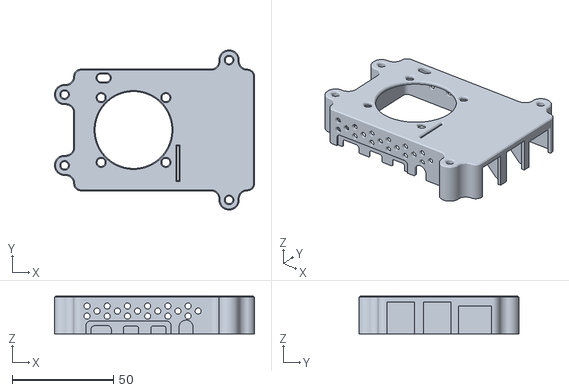
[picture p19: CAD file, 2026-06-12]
Stls/Top_Case.STL
99.0 x 79.2 x 18.6

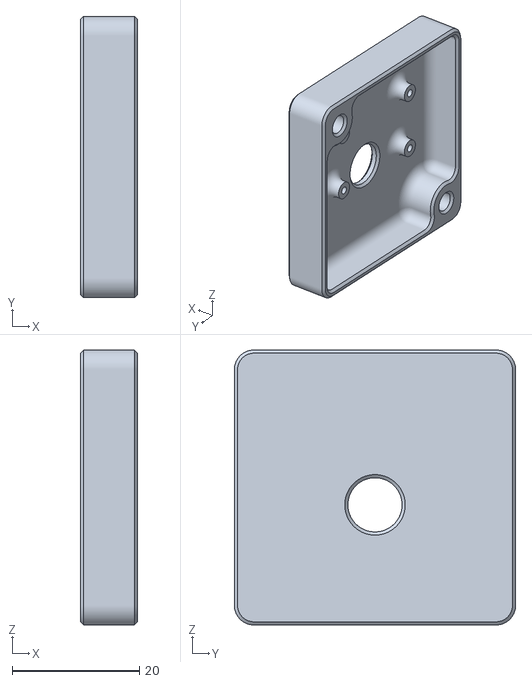
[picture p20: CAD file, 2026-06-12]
Stls/Camera_Cover.STL
9.00 x 44.2 x 43.2

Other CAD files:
Stls/Arducam+1080p+Day+Night+USB+Camera+Case/baby-camera-rear-fillet.stl

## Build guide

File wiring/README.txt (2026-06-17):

GPIO wiring diagrams for the BB Dice Tracker (regenerated 2026-06-17).

gpio_wiring_diagram.png  - PRIMARY. Full 40-pin Pi header with the real
                           per-pin pinout (3V3/5V/GND/GPIO labels), plus
                           the components + colored wires.
gpio_wiring_alt.png      - alternate layout, same pin map (compact header).

AUTHORITATIVE SOURCE: DESIGN.md "LOCKED GPIO pin map" table.
The images are PIN-MAP visual aids. Every GPIO/physical-pin pair AND the
40-pin header pinout were verified against the table + the official Pi
pinout 2026-06-17 (no hallucinated pins this time). BUT the images are
NOT literal point-to-point routing -- the drawn wires are decorative;
follow the LABELS and the DESIGN.md table, not the pixel a wire touches.

BUTTON WIRE COLORS (signal wire to GPIO; ground wire = WHITE):
  P1 Confirm = BLUE   -> GPIO17 (Pin 11)
  P2 Confirm = GREEN  -> GPIO27 (Pin 13)
  Reject     = RED    -> GPIO22 (Pin 15)
  Undo       = YELLOW -> GPIO23 (Pin 16)

OLED VCC = 3V3 (Pin 1, never 5V); OLED GND = any real ground pin
(6, 9, 14, 20, 25, 30, 34, 39). OLED bus shared except CS:
OLED-1 CS = GPIO8/CE0 (Pin 24), OLED-2 CS = GPIO7/CE1 (Pin 26).

Pins are software-verified (no SPI-bus collision, all drivable by
gpiozero/RPi.GPIO + luma.oled). Buttons: switch->GND, internal pull-up.
LEDs: red->GPIO, black->GND (inline resistor already present).

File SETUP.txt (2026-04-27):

====================================================
  BLOOD BOWL DICE TRACKER — SETUP INSTRUCTIONS
====================================================

REQUIREMENTS
------------
- Windows 10 / 11
- Python 3.10 or 3.11  (https://www.python.org/downloads/)
- Your USB Google/Blink camera plugged in
- ~2 GB free disk space (for PyTorch + EasyOCR models)

STEP 1 — Install Python packages
---------------------------------
Open a Command Prompt in this folder (Dice Code) and run:

    pip install -r requirements.txt

This installs OpenCV, PyTorch, EasyOCR, and Pillow.
It may take several minutes the first time.

STEP 2 — Prepare training images
----------------------------------
Run this once to crop and augment your reference dice photos:

    python classifier/prepare_training_data.py

You should see output like:
    Done. 168 images written, 0 skipped.

STEP 3 — Train the block dice classifier
------------------------------------------
Run:

    python classifier/train_block_dice.py

This trains the neural network on your dice images.
Takes 1-3 minutes.  You should see:
    Epoch 40/40  loss=0.0xxx  val_acc=100.0%
    Model saved to: classifier/block_dice_model.pt

STEP 4 — Test your camera
---------------------------
To find your camera index (usually 0):

    python detection/camera.py

A live preview window opens.  Press Q to close.
If it opens a black screen try:  python detection/camera.py  (edit source=1 in the file)

STEP 5 — Run the tracker
--------------------------
Basic start (Player 1 vs Player 2, USB camera 0):

    python main.py

With custom player names:

    python main.py --player1 "Team Chaos" --player2 "Team Order"

Different camera index:

    python main.py --camera 1

Resume a saved game:

    python main.py --load session.json

CONTROLS (in the tracker window)
----------------------------------
SPACE       Confirm the current roll and record it
BACKSPACE   Undo the last recorded roll
1           Set Player 1 as the active roller
2           Set Player 2 as the active roller
N           Manually advance to next turn
S           Save game (creates session.json + session.csv)
Q / ESC     Quit (will ask if you want to save)

HOW IT WORKS
------------
1. Camera watches the dice tray continuously.
2. When dice stop moving for ~0.5 seconds, the window border flashes GREEN.
3. The system reads each die and shows the results on screen.
4. Press SPACE to confirm the roll — it gets added to the scoresheet.
5. After 16 turns the final scores are displayed and you can export to CSV.

FUTURE — ARDUINO / WIRELESS CAMERA (Phase 2)
---------------------------------------------
When you get the specs of your friend's Arduino camera, run:

    python main.py --camera http://192.168.x.x/stream

(replace the IP with whatever the Arduino camera serves)
No other code changes needed.

FILES CREATED DURING PLAY
--------------------------
session.json    Full game state (can be loaded to resume)
session.csv     Roll-by-roll export for spreadsheet analysis

TROUBLESHOOTING
---------------
"Cannot open camera source: 0"
  -> Try --camera 1 or --camera 2
  -> Make sure no other app (Teams, Zoom, OBS) is using the camera

"Model not found" error
  -> Re-run steps 2 and 3

Block dice misidentified
  -> Adjust camera height / lighting
  -> Add more training photos to training_data/<class>/ and re-train

d8/d16 not distinguished correctly
  -> Edit detection/classify_die_type.py
  -> Adjust D16_MIN_AREA_FRACTION and D8_MIN_AREA_FRACTION values

====================================================

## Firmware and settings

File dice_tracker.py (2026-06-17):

"""
dice_tracker.py
---------------
The actual Blood Bowl Dice Tracker app — the production runtime that wires
together camera capture, YOLO detection, supervision-based smoothing, and
the SETUP.txt UX (settle -> SPACE to confirm -> log).

This replaces the live_detect_* dev scripts. Those stay in training/ for
future debugging; this is the entrypoint.

Architecture per session:
    YOLO ONNX (per dice type)
      -> sv.ByteTrack + DetectionsSmoother (per-frame stability)
      -> LabelStabilizer (per-tracker-id class majority vote)
      -> settle detection (all tracker labels stable AND >0 dice)
      -> SPACE = confirm and log; BACKSPACE = undo last; R = reject (for retrain)
      -> tracker resets between rolls

Controls (in preview window):
    1   set Player 1 as active roller
    2   set Player 2 as active roller
    B   switch to block model        (block dice)
    D   switch to d6 model           (BB d6)
    X   switch to d16 model          (D16 trapezohedron)
    SPACE   confirm settled roll, log it under active player
    BACKSPACE  undo last logged roll
    R   reject current settled read; save frame for future retraining
    S   save session to disk (session.json + session.csv)
    L   load session.json (resume earlier game)
    Q   quit (asks to save if there are unsaved rolls)

Output:
    session.json                  full session state for reload
    session.csv                   tabular roll log
    retrain_candidates/<type>/    frames + JSON the model got wrong
"""

import csv
import json
import os
import sys
import time
from collections import Counter, defaultdict, deque
from pathlib import Path

import cv2
import numpy as np

import db
import d16_geometry
import inference_backend as backend
from inference_backend import predict_detections
from dice_types import CLASS_TO_TYPE, majority_type

ROOT       = Path(__file__).parent
MODELS_DIR = ROOT / "training" / "models"
SESSION_JSON = ROOT / "session.json"
SESSION_CSV  = ROOT / "session.csv"
RETRAIN_DIR  = ROOT / "retrain_candidates"
RETRAIN_DIR.mkdir(exist_ok=True)
(RETRAIN_DIR / "block").mkdir(exist_ok=True)
(RETRAIN_DIR / "d6").mkdir(exist_ok=True)
(RETRAIN_DIR / "d16").mkdir(exist_ok=True)

CAMERA_INDEX = 0
RESOLUTION   = (1280, 720)
CONF_THRESHOLD = 0.40

# ── IR-mode self-check ──────────────────────────────────────────────────────
# The models are trained exclusively on IR-mode frames. Day-mode frames
# (photoresistor exposed to bright light) are out-of-distribution and
# silently degrade accuracy — the May 13 morning session ran in day mode
# without anyone noticing. Measured IN-TRAY on reference frames (2026-06-11):
# true IR frames = 4.0-5.2 (chroma noise on the tray's high-contrast
# graphics), day-mode frames = ~10.8-11. Threshold sits between the bands.
# The tray ROI is used (when tray_roi.json exists) so ambient lamp spill on
# the floor around the rig can't trip a false day-mode warning.
DAY_MODE_DEVIATION = 8.0
IR_CHECK_INTERVAL  = 90    # frames between live re-checks (~3s at 30fps)
TRAY_ROI_FILE = ROOT / "tray_roi.json"


def _load_tray_roi():
    """Tray rect from tray_roi.json scaled to RESOLUTION, or None."""
    try:
        d = json.loads(TRAY_ROI_FILE.read_text())
        sx = RESOLUTION[0] / d["frame_width"]
        sy = RESOLUTION[1] / d["frame_height"]
        return (int(d["x"] * sx), int(d["y"] * sy),
                int(d["w"] * sx), int(d["h"] * sy))
    except Exception:
        return None


_TRAY_ROI = _load_tray_roi()


def load_model_meta(stem: str) -> dict:
    """Sidecar metadata for models/<stem>.onnx — currently whether the
    model was trained tray-cropped (models/<stem>.onnx.json, written by
    train_all.py). Missing sidecar = full-frame model (the default for
    every model trained before the 2026-06 crop retrain)."""
    meta = {"tray_crop": False}
    try:
        meta.update(json.loads(
            (MODELS_DIR / f"{stem}.onnx.json").read_text()))
    except Exception:
        pass
    return meta


def tray_crop_rect(actual_w: int, actual_h: int) -> tuple | None:
    """Tray ROI (x, y, w, h) scaled to the actual capture resolution —
    the inference crop for tray-crop-trained models."""
    try:
        d = json.loads(TRAY_ROI_FILE.read_text())
        sx = actual_w / d["frame_width"]
        sy = actual_h / d["frame_height"]
        return (int(d["x"] * sx), int(d["y"] * sy),
                int(d["w"] * sx), int(d["h"] * sy))
    except Exception:
        return None


# predict_detections is provided by inference_backend (re-exported above so
# eval_harness's `from dice_tracker import predict_detections` keeps working).
# It crops/pads to the tray ROI for crop-trained models and returns
# full-frame coords — identical geometry on the ultralytics (PC) and
# torch-free onnx (Pi) backends.


def color_deviation(frame) -> float:
    """Mean absolute channel deviation from grayscale (0 = pure mono),
    measured inside the tray ROI when available."""
    if _TRAY_ROI is not None:
        x, y, w, h = _TRAY_ROI
        frame = frame[y:y + h, x:x + w]
    small = frame[::4, ::4].astype(np.float32)
    b, g, r = small[..., 0], small[..., 1], small[..., 2]
    return float((np.abs(r - g).mean() + np.abs(g - b).mean()
                  + np.abs(r - b).mean()) / 3)


def alignment_check(cap, actual_w: int, actual_h: int) -> bool:
    """Pre-flight camera alignment: overlay the saved tray-corner reference
    (tray_roi.json) on the live feed so the camera can be adjusted back to
    the training-time position whenever the rig has been moved. The model
    only knows the calibrated perspective — this runs before every session.

    SPACE/ENTER = aligned, continue.  Q/ESC = abort.
    Returns True to proceed, False if the user aborted.
    """
    try:
        d = json.loads(TRAY_ROI_FILE.read_text())
        sx = actual_w / d["frame_width"]
        sy = actual_h / d["frame_height"]
        pts = [(int(cx * sx), int(cy * sy)) for cx, cy in d["corners"]]
    except Exception:
        print("No tray_roi.json reference — skipping alignment check.")
        return True

    print("Alignment check: match the live tray edges to the GREEN outline")
    print("(adjust the camera arm if needed), then press SPACE to continue.")
    # NOTE: window titles and cv2.putText HUD strings must be plain ASCII.
    # Non-ASCII (em dashes etc.) gets mangled on Windows and can even create
    # DUPLICATE ghost windows that destroyWindow can't close.
    win = "Alignment check - match tray to GREEN outline, SPACE to continue"
    cv2.namedWindow(win, cv2.WINDOW_NORMAL)
    cv2.resizeWindow(win, actual_w, actual_h)

    proceed = None
    while proceed is None:
        ret, frame = cap.read()
        if not ret:
            continue
        for i in range(4):
            p1, p2 = pts[i], pts[(i + 1) % 4]
            cv2.line(frame, p1, p2, (0, 255, 0), 3)
            cv2.circle(frame, p1, 8, (0, 255, 0), -1)
            cv2.putText(frame, ["TL", "TR", "BR", "BL"][i],
                        (p1[0] + 12, p1[1] - 12),
                        cv2.FONT_HERSHEY_SIMPLEX, 0.8, (0, 255, 0), 2)
        hud_line(frame, "ALIGNMENT CHECK - match tray edges to green outline",
                 25, color=(0, 255, 0), scale=0.7)
        hud_line(frame, "SPACE/ENTER = aligned, start  |  Q = quit",
                 50, color=(0, 255, 255), scale=0.6)
        cv2.imshow(win, frame)
        key = cv2.waitKey(1) & 0xFF
        if key in (32, 13):
            proceed = True
        elif key in (ord('q'), 27):
            proceed = False
    cv2.destroyWindow(win)
    # On Windows the window only actually closes once the GUI event queue
    # is pumped — destroyWindow alone leaves a frozen ghost window.
    for _ in range(5):
        cv2.waitKey(1)
    return proceed


def _draw_align_overlay(frame, actual_w, actual_h):
    """Draw the green tray-corner reference on a frame (shared by the GUI
    and headless/phone alignment paths). Returns the annotated copy, or the
    original if no tray_roi.json reference exists."""
    try:
        d = json.loads(TRAY_ROI_FILE.read_text())
        sx = actual_w / d["frame_width"]
        sy = actual_h / d["frame_height"]
        pts = [(int(cx * sx), int(cy * sy)) for cx, cy in d["corners"]]
    except Exception:
        return frame
    out = frame.copy()
    for i in range(4):
        p1, p2 = pts[i], pts[(i + 1) % 4]
        cv2.line(out, p1, p2, (0, 255, 0), 3)
        cv2.circle(out, p1, 8, (0, 255, 0), -1)
    hud_line(out, "Match tray to GREEN outline, then Confirm on phone",
             25, color=(0, 255, 0), scale=0.7)
    return out


def _save_tray_roi_corners(corners, frame_w, frame_h):
    """Rewrite tray_roi.json from 4 phone-tapped corners. Stores the
    quad (for the green overlay) AND its axis-aligned bounding box
    (x/y/w/h — the inference crop the model is trained on). frame_w/h are
    the pixel size the corners were tapped in, saved as frame_width/height
    so the scale-on-load math stays correct at any capture resolution."""
    xs = [c[0] for c in corners]
    ys = [c[1] for c in corners]
    x, y = min(xs), min(ys)
    w, h = max(xs) - x, max(ys) - y
    data = {
        "x": int(x), "y": int(y), "w": int(w), "h": int(h),
        "frame_width": int(frame_w), "frame_height": int(frame_h),
        "corners": [[int(c[0]), int(c[1])] for c in corners],
    }
    TRAY_ROI_FILE.write_text(json.dumps(data, indent=2))
    print(f"[align] tray_roi.json updated from phone: bbox=({x},{y},{w},{h})")


def alignment_check_web(cap, actual_w, actual_h, web_control) -> bool:
    """Headless alignment: stream the green-outline overlay to the phone
    (/align) and wait for the operator to tap Confirm. No monitor needed —
    the sealed rig's only screen is the phone. Returns True to proceed.

    Falls through (returns True) if there's no tray_roi.json reference or
    no web control to drive the phone UI."""
    if web_control is None:
        print("No web control — skipping alignment (headless).")
        return True
    if not TRAY_ROI_FILE.exists():
        print("No tray_roi.json reference — skipping alignment check.")
        return True
    print("Headless alignment: open  /align  on the phone, match the tray")
    print("to the green outline, then tap Confirm.")
    web_control.take_alignment()   # clear any stale confirm
    web_control.take_new_corners()  # clear any stale corner post
    web_control.set_aligning(True)  # /align shows the live outline now
    while True:
        ret, frame = cap.read()
        if not ret:
            continue
        # Phone re-set the tray corners? Rewrite tray_roi.json so the very
        # next overlay (and the crop ROI once we proceed) reflects them.
        nc = web_control.take_new_corners()
        if nc is not None:
            corners, fw, fh = nc
            try:
                _save_tray_roi_corners(corners, fw, fh)
            except Exception as e:
                print(f"[align] failed to save corners: {e}")
        overlay = _draw_align_overlay(frame, actual_w, actual_h)
        ok, buf = cv2.imencode(".jpg", overlay,
                               [cv2.IMWRITE_JPEG_QUALITY, 70])
        if ok:
            web_control.set_frame(buf.tobytes())
        if web_control.take_alignment():
            print("Alignment confirmed from phone.")
            web_control.set_aligning(False)
            return True


# ── Smoothing / settle settings ─────────────────────────────────────────────
SMOOTHER_LENGTH    = 5
LABEL_HISTORY_LEN  = 8
LABEL_MIN_VOTES    = 4
SETTLE_REQUIRES_ALL_STABLE = True   # green flash only when every die is stable
# The detection COUNT must be constant this many consecutive frames before
# settle. Without it, a die flickering in/out near the conf threshold lets
# the roll settle during an "out" frame and the die is dropped from the
# read (2026-06-11 eval: 16/50 rolls lost dice this way).
#
# This is a FRAME count, so its real-time meaning depends on FPS: the PC
# ran ~30fps (10 frames ~= 0.33s), but the Pi's CPU-only onnxruntime is
# much slower (~5fps), making 10 frames ~= 2s — the sluggish settle seen
# live 2026-06-15. SETTLE_SECONDS is the target dwell time; the frame count
# is derived from the measured FPS at startup so settle feels the same on
# both. (Floor of 4 frames so a brief flicker can't settle a moving die.)
SETTLE_SECONDS = 0.5
COUNT_STABLE_FRAMES = 10   # default until FPS is measured at startup

# Uncertainty marker thresholds — PER DICE TYPE, recalibrated 2026-06-12
# for the tray-crop combined model (its confidence scale runs lower than
# the old full-frame model: block correct reads average 0.74 vs 0.90).
# From the live eval sessions:
#   block: 66/66 correct, conf p10=0.53 -> 0.60 keeps the historical ~20%
#          flag-noise rate (no wrong reads observed to calibrate against)
#   d16:   correct mean 0.86 vs wrong 0.69 -> 0.80 catches 67% of wrong
#          reads while flagging only 12% of correct ones
#   d6:    no live data with this model yet — block's distribution is the
#          closest proxy; recalibrate after the first d6 session
# Labels below the threshold show orange with a "?" so the player's eye
# is drawn to questionable dice BEFORE confirming (nudge to re-read).
# This is the on-screen precursor of the OLED uncertainty markers.
CONF_UNCERTAIN = {"block": 0.60, "d6": 0.60, "d16": 0.80}
CONF_UNCERTAIN_DEFAULT = 0.80


def uncertain_threshold(label: str) -> float:
    return CONF_UNCERTAIN.get(CLASS_TO_TYPE.get(label, ""),
                              CONF_UNCERTAIN_DEFAULT)

WEB_PORT = 5000

# Nudge-to-resettle: once settled, if ANY tracked die's center moves more
# than this many pixels since the lock, release back to "watching" so the
# system re-reads.  Lets a player nudge a single misread die to retry
# without disturbing the rest of the roll.
NUDGE_PIXEL_THRESHOLD = 20


# ── Label stabilizer (per-tracker-id majority vote) ─────────────────────────
class LabelStabilizer:
    def __init__(self, history_len=LABEL_HISTORY_LEN,
                 min_votes=LABEL_MIN_VOTES):
        self.history_len = history_len
        self.min_votes   = min_votes
        self._hist = defaultdict(lambda: deque(maxlen=self.history_len))

    def reset(self):
        self._hist.clear()

    def update(self, tracker_ids, class_ids, confidences):
        out = []
        for tid, cid, conf in zip(tracker_ids, class_ids, confidences):
            self._hist[tid].append((cid, conf))
            votes = Counter(v[0] for v in self._hist[tid])
            top_class, top_n = votes.most_common(1)[0]
            mean_conf = (sum(v[1] for v in self._hist[tid] if v[0] == top_class)
                         / max(top_n, 1))
            stable = top_n >= self.min_votes
            out.append((int(top_class), float(mean_conf), bool(stable)))
        return out


def make_tracker():
    # ByteTrack (PC) or a numpy IoU tracker (Pi) — selected by the backend.
    return backend.make_tracker()


# ── Session state ───────────────────────────────────────────────────────────
class Session:
    def __init__(self):
        self.rolls: list[dict] = []
        self.next_roll_id      = 1
        self.active_player     = "P1"
        self.player1_name      = "Player 1"
        self.player2_name      = "Player 2"
        self.started_at        = time.time()

    def record(self, dice_type: str, results: list[str],
               confidences: list[float],
               rejected: bool = False,
               raw_image_path: str | None = None) -> dict:
        roll = {
            "roll_id":         self.next_roll_id,
            "timestamp":       time.time(),
            "player":          self.active_player,
            "dice_type":       dice_type,
            "results":         results,
            "confidences":     [round(c, 3) for c in confidences],
            "rejected":        rejected,
            "raw_image_path":  raw_image_path,
        }
        self.rolls.append(roll)
        self.next_roll_id += 1
        return roll

    def undo(self) -> dict | None:
        if not self.rolls:
            return None
        return self.rolls.pop()

    def save(self):
        payload = {
            "started_at":     self.started_at,
            "saved_at":       time.time(),
            "active_player":  self.active_player,
            "player1_name":   self.player1_name,
            "player2_name":   self.player2_name,
            "next_roll_id":   self.next_roll_id,
            "rolls":          self.rolls,
        }
        SESSION_JSON.write_text(json.dumps(payload, indent=2))

        with open(SESSION_CSV, "w", newline="") as f:
            w = csv.writer(f)
            w.writerow(["roll_id", "timestamp", "player", "dice_type",
                        "results", "confidences", "rejected"])
            for r in self.rolls:
                w.writerow([
                    r["roll_id"], r["timestamp"], r["player"], r["dice_type"],
                    "|".join(r["results"]),
                    "|".join(str(c) for c in r["confidences"]),
                    r["rejected"],
                ])

    def load(self):
        if not SESSION_JSON.exists():
            print("No session.json to load.")
            return
        d = json.loads(SESSION_JSON.read_text())
        self.started_at     = d.get("started_at", time.time())
        self.active_player  = d.get("active_player", "P1")
        self.player1_name   = d.get("player1_name", "Player 1")
        self.player2_name   = d.get("player2_name", "Player 2")
        self.next_roll_id   = d.get("next_roll_id", 1)
        self.rolls          = d.get("rolls", [])
        print(f"Loaded session: {len(self.rolls)} rolls, "
              f"next id = {self.next_roll_id}")


# ── Drawing helpers ─────────────────────────────────────────────────────────
def draw_detections(frame, detections, model, label_states):
    out = frame.copy()
    for i in range(len(detections)):
        x1, y1, x2, y2 = [int(v) for v in detections.xyxy[i]]
        tid = (int(detections.tracker_id[i])
               if detections.tracker_id is not None else -1)
        cid, conf, stable = label_states[i]
        cls_name = model.names.get(cid, str(cid))
        if stable and conf >= uncertain_threshold(cls_name):
            color = (0, 255, 255)        # yellow: stable + confident
            thickness = 3
            text = f"#{tid} {cls_name} {int(round(conf*100))}%"
        elif stable:
            color = (0, 140, 255)        # orange: stable but UNCERTAIN
            thickness = 3
            text = f"#{tid} {cls_name}? {int(round(conf*100))}% NUDGE?"
        else:
            color = (140, 140, 140)      # gray: still settling
            thickness = 2
            text = f"#{tid} {cls_name}? {int(round(conf*100))}%"
        cv2.rectangle(out, (x1, y1), (x2, y2), color, thickness)
        (tw, th), _ = cv2.getTextSize(text, cv2.FONT_HERSHEY_SIMPLEX, 0.55, 1)
        cv2.rectangle(out, (x1, y1 - th - 8), (x1 + tw + 6, y1), color, -1)
        cv2.putText(out, text, (x1 + 3, y1 - 5),
                    cv2.FONT_HERSHEY_SIMPLEX, 0.55, (0, 0, 0), 1)
    return out


def hud_line(frame, text, y, color=(255, 255, 255), scale=0.55):
    cv2.putText(frame, text, (10, y), cv2.FONT_HERSHEY_SIMPLEX,
                scale, (0, 0, 0), 4)
    cv2.putText(frame, text, (10, y), cv2.FONT_HERSHEY_SIMPLEX,
                scale, color, 1)


# ── Main loop ───────────────────────────────────────────────────────────────
def _has_display() -> bool:
    """True only if an OpenCV GUI window can actually open. The production
    Pi rig is a sealed box with NO monitor (phone is the only screen), so
    this is normally False there."""
    import os
    if sys.platform.startswith("linux") and not os.environ.get("DISPLAY"):
        return False
    try:
        probe = "._disp_probe"
        cv2.namedWindow(probe, cv2.WINDOW_NORMAL)
        cv2.destroyWindow(probe)
        for _ in range(3):
            cv2.waitKey(1)
        return True
    except Exception:
        return False
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

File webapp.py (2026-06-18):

"""
webapp.py
---------
Phone web UI for the Blood Bowl Dice Tracker (Flask).

Two halves:

1. LIVE CONTROL (only when attached to a running dice_tracker.py):
   - pick the dice type for the next roll (Block / D6 / D16)
   - set the active rolling player (until the physical buttons exist)
   - live status: tracker state, last roll, roll count

2. GAME REVIEW (works any time, including standalone on the PC):
   - list of games
   - per-game roll log with confidences, reject/edit flags
   - THE END-OF-GAME RECORD: per-player, per-dice-type face tallies
   - post-game corrections: edit a roll's faces (flagged 'edited'),
     delete a roll
   - CSV export per game

Run standalone (review only):       python webapp.py [--port 5000]
Attached mode is started automatically by dice_tracker.py.

Phone access: http://<pi-or-pc-ip>:5000/  (same WiFi / hotspot).
"""

import csv
import html
import io
import json
import math
import socket
import threading
import time

from flask import (Flask, Response, redirect, render_template_string,
                   request, url_for)

import db
import tourplay
from dice_types import TYPE_FACES as FACES

DICE_TYPES = ["auto", "block", "d6", "d16"]


class WebControl:
    """Thread-safe mailbox between the Flask thread and the tracker loop.

    The web side writes requests (requested_type / requested_player);
    the tracker loop applies them and clears them, and refreshes `status`
    every frame.
    """

    def __init__(self):
        self._lock = threading.Lock()
        self.requested_type: str | None = None
        self.requested_player: str | None = None
        self.requested_action: str | None = None   # reject / undo / confirm
        self.requested_names: tuple | None = None   # (p1_name, p2_name)
        self.status: dict = {}
        # Headless support: the tracker pushes the latest JPEG here so the
        # phone can show a live view (camera alignment + monitoring) without
        # any monitor on the Pi. align_confirmed is set when the operator
        # taps Confirm on the phone alignment screen.
        self.latest_jpeg: bytes | None = None
        self.align_confirmed: bool = False
        # Phone tap-4-corners re-calibration: the phone posts 4 tray
        # corners (in streamed-frame pixel coords); the tracker loop picks
        # them up, rewrites tray_roi.json, and reloads the ROI live.
        self.new_corners: list | None = None
        # True only while the startup alignment loop is streaming the green
        # outline. Once the session goes live the stream carries the live
        # read instead, so /align shows a "session running" notice rather
        # than a confusing broken image. Alignment is a startup-only step.
        self.aligning: bool = False

    def request_type(self, dice_type: str):
        with self._lock:
            self.requested_type = dice_type

    def request_player(self, player: str):
        with self._lock:
            self.requested_player = player

    def request_action(self, action: str):
        with self._lock:
            self.requested_action = action

    def request_names(self, p1: str, p2: str):
        with self._lock:
            self.requested_names = (p1, p2)

    def take_names(self) -> tuple | None:
        with self._lock:
            n = self.requested_names
            self.requested_names = None
            return n

    def take_requests(self) -> tuple[str | None, str | None]:
        with self._lock:
            t, p = self.requested_type, self.requested_player
            self.requested_type = None
            self.requested_player = None
            return t, p

    def take_action(self) -> str | None:
        with self._lock:
            a = self.requested_action
            self.requested_action = None
            return a

    def set_frame(self, jpeg: bytes):
        with self._lock:
            self.latest_jpeg = jpeg

    def get_frame(self) -> bytes | None:
        with self._lock:
            return self.latest_jpeg

    def confirm_alignment(self):
        with self._lock:
            self.align_confirmed = True

    def set_new_corners(self, corners: list, frame_w: int, frame_h: int):
        with self._lock:
            self.new_corners = (corners, frame_w, frame_h)

    def take_new_corners(self):
        with self._lock:
            c = self.new_corners
            self.new_corners = None
            return c

    def take_alignment(self) -> bool:
        with self._lock:
            v = self.align_confirmed
            self.align_confirmed = False
            return v

    def set_aligning(self, on: bool):
        with self._lock:
            self.aligning = on

    def is_aligning(self) -> bool:
        with self._lock:
            return self.aligning

    def update_status(self, **kwargs):
        with self._lock:
            self.status = dict(kwargs, updated_at=time.time())

    def get_status(self) -> dict:
        with self._lock:
            return dict(self.status)
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

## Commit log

2026-04-27 Initial commit - Blood Bowl dice tracker
    [session.csv]
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2026-06-12 Major checkpoint: YOLO production stack, eval harness, DB + web app, combined auto-type model
    Detection / accuracy:
    - dice_tracker.py: production app (YOLO + supervision ByteTrack/smoother +
    LabelStabilizer, settle-confirm UX, nudge-to-resettle)
    - Settle-race fix: COUNT_STABLE_FRAMES=10 (missed-dice rolls 32% -> 8%)
    - IR-mode self-check at startup + live re-check (day-mode guard)
    - Camera alignment pre-flight built into every session
    - HUD uncertainty markers at 0.85 confidence (eval-calibrated)
    - eval_harness.py: ground-truth per-die accuracy measurement with
    Wilson CIs, confusion pairs, miss-frame banking for retraining
    Combined model (auto dice-type detection):
    - training/merge_datas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
    [Bottom_Case.STL, Camera_Base.STL, Camera_Cover.STL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]
2026-06-12 End-of-game dice record styled after BB3 report, with true-to-dice icons
    - Per-player banner + full face inventory: d6 row (black dice, white
    pips, BB-logo six), block row (spiked-ring SVG icons drawn from the
    actual 2025 starter dice: push arrow, both-down skull+burst, stumble
    exclamation, layered POW starburst, player-down open-ring skull),
    d16 row (16 numbered cream dice, always shown)
    - Each die is a centered column: icon, count, label; zero counts dimmed
    - lan_ip(): print the real phone-reachable URL at startup, preferring
    home-LAN ranges and skipping VPN/CGNAT adapters (DHCP moved the PC
    address overnight and Safari could not connect to the stale IP)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
    [dice_tracker.py, webapp.py]
2026-06-12 Refresh all docs: DESIGN.md status/layout/priorities, real README, HANDOFF.md
    - DESIGN.md: 2026-06-12 status header, current repo layout, prioritized
    next-up list (combined-model live eval, pow tray-crop retrain,
    GPIO/OLED, Pi port)
    - README.md: proper project readme (was a one-liner)
    - HANDOFF.md: paste-able session hand-off prompt with locked rules,
    current state, priorities, and Windows/CV gotchas
2026-06-12 Synthetic-data retrain pipeline + tray-crop model (92% bar passed) + D16 adjacency layer
    Copy-paste synthetic training data from real pixels (training/synth_dice.py):
    per-session median-stack backgrounds, background-subtraction die cutouts,
    pow-weighted 3x, wall/corner-biased placement, whole-die d16 units, no flips.
    Banked retrain_candidates frames auto-labeled from eval ground truth
    (auto_label_rejects.py). Dataset assembled tray-cropped from raw capture
    frames with per-session ECC tray alignment (crop_common.py,
    build_crop_dataset.py); valid/test are real frames only.
    combined_crop YOLOv11n passes the locked bar on all types (val mean mAP@50:
    block 94.1 / d6 98.4 / d16 92.7; test 99.5 /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
    [d16_geometry.py, dice_tracker.py, eval_harness.py]
2026-06-12 d16 eval scores the ROLLED VALUE, not per-face boxes
    Field feedback from the first live d16 eval: glyph arcs do not run
    left-to-right, the overlay covered the die, and the per-face protocol
    asked the operator to map numbers onto boxes they cannot see clearly.
    The product metric is the rolled value anyway.
    The harness now clusters face boxes into dice, runs the verified
    d16_geometry adjacency layer (deduction + impossible-combo detection),
    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
2026-06-13 d16 settle gates on stable boxes only - transient glyph flicker no longer blocks settle
    Field finding from the first combined_crop d16 eval: a d16 die shows 2-3
    small glyph boxes and the marginal one flickers at the conf threshold.
    The raw-count stability window (COUNT_STABLE_FRAMES=10) reset on every
    flicker, so physically settled rolls took ages to settle in software or
    never did.
    For d16 (eval harness and production tracker): settle requires the
    STABLE-box set and its die-cluster count to hold for the window;
    transient boxes are ignored and excluded from the locked read and from
    the nudge-release snapshot. A box that persists long enough to win the
    label vote joins the stable set and set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
    [dice_tracker.py, eval_harness.py]
2026-06-13 Pad the tray-crop inference window; handle 4-glyph d16 clusters
    Bottom-wall dice project their faces below the tray ROI rect (camera
    sits north of the tray) - the crop-trained model could not see a die in
    the bottom corners at all. The ONNX sidecar now carries pad/pad_bottom
    (8px around, +40px bottom) and predict_detections expands the crop
    accordingly; die scale shifts ~4%, well inside training augmentation.
    d16_geometry.analyze_roll keeps the 3 most confident glyphs when a
    cluster has 4+ boxes instead of returning unknown.
    Offline check on the 29 banked d16 miss frames: 12% baseline -> new
    model reads 17/29 of the baseline FAILURES correctly, single-frame,
    no smoothing stack.
    Co-Authore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
    [d16_geometry.py, dice_tracker.py]
2026-06-13 Ship the tray-crop retrain: 100% block live, d16 12%->65%, per-type uncertainty thresholds
    Live eval results (eval_sessions/, 2026-06-12):
    - block with combined_crop: 66/66 per-die = 100% (CI 94.5-100), POW
    18/18 - the proven resolution problem is fixed. 3/25 rolls still
    dropped a die from the read (count mismatch, frames banked).
    - d16 baseline with the old full-frame model (first ever live d16
    number): 3/25 = 12%, two-digit glyphs systematically read as
    one-digit. d16 with combined_crop + verified adjacency layer:
    17/26 = 65% value accuracy, ~88% correct-or-flagged.
    Deployed combined_crop as production combined.onnx (sidecar carries
    tray_crop + pad); old model kept as combined_f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
    [diag_d16.py, dice_tracker.py]
2026-06-13 Full-circle d16 synth rotation + drop degenerate label boxes
    Two fixes for the d16 full-rotation retrain:
    - synth_dice ROT_D16_MAX 12 -> 180. The d16 capture sessions were posed
    (glyphs biased upright), so the first crop model misread rotated
    digits live (9<->16, 8<->1 ring-neighbor swaps). Spinning the whole
    die unit is physically valid from the near-overhead camera and keeps
    the three glyph boxes geometrically married.
    - write_yolo_boxes now clamps boxes to the image and drops sub-3px
    slivers. A glyph clipped to ~0px tall at the crop edge produced a
    degenerate instance that crashed Ultralytics' affine augmentation on
    Windows at epoch 25 of the first full-rotation run. Adds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
2026-06-13 Deploy full-rotation d16 crop model; refresh handoff
    Second crop-model iteration passed both gates and is now production
    combined.onnx: val_per_type block 93.6 / d6 99.2 / d16 92.7 mean
    mAP@50, and 24/38 on the banked d16 truth frames (up from the v1 crop
    model's 20/38). Prior crop model kept as combined_crop_v1_20260612.onnx.
2026-06-14 Lock GPIO/OLED pin map + add verified wiring diagrams
    The 4 button + 4 LED GPIO pins were never assigned in DESIGN.md (only the
    OLED SPI bus was). Locked them: buttons P1/P2/Reject/Undo = GPIO17/27/22/23
    (switch->GND, internal pull-up), LEDs = GPIO5/6/13/19 (red->GPIO,
    black->GND, inline resistor). Verified software-clean -- no SPI-bus
    collision, all drivable by gpiozero/RPi.GPIO + luma.oled. Written into
    DESIGN.md as the authoritative LOCKED GPIO pin map.
    wiring/ holds two top-down diagrams (Higgsfield nano_banana_pro) with
    every GPIO/physical-pin label verified against the locked table. README
    notes they are accurate PIN MAPS, not literal point-to-point routing
    (the model can't trace nets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
2026-06-14 Pi port: torch-free inference backend, GPIO/OLED layer, deploy tooling
    Moves the tracker onto the portable Pi rig. ultralytics + supervision
    depend on torch (too heavy for the Pi), so the detection stack is now
    pluggable:
    - onnx_backend.py: pure onnxruntime + numpy. Custom YOLOv11 decoder
    (output0 [1,31,8400]), letterbox preprocess, agnostic NMS, an IoU
    tracker (ByteTrack-equivalent) and box smoother. Class names read from
    ONNX metadata -- no ultralytics needed. Bit-for-bit parity with the
    ultralytics path on banked frames (<=0.0005 conf, <=0.1px box).
    - inference_backend.py: auto-selects ultralytics (PC, torch present) vs
    onnx (Pi). dice_tracker / eval_harness / diag_d16 refactor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
    [diag_d16.py, dice_tracker.py, eval_harness.py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]
2026-06-14 Correct OLED power/GND in pin map; flag wiring-image 'Pin 7' error
    OLED VCC is 3V3 (pin 1), never 5V -- SSD1309 is a 3.3V part. OLED GND is
    any ground pin (6/9/14/20/25/30/34/39, one shared rail); the table's
    vague "9/25/..." is now explicit.
    The v2 wiring image hallucinated a "GND (Pin 7)" label -- physical pin 7
    is GPIO4, not a ground. Flagged in DESIGN.md and wiring/README so it
    isn't trusted; the DESIGN.md table remains authoritative. Also corrected
    the README's overclaim that every label was verified (the standalone GND
    labels weren't, which is how Pin 7 slipped through).
2026-06-14 Headless rig: no monitor, phone-driven alignment (honor sealed-box design)
    DESIGN.md is explicit that the rig is a sealed box with no monitor -- the
    phone is the only screen. The initial Pi port wrongly carried over the dev
    OpenCV preview window + on-screen alignment overlay; corrected here.
    dice_tracker now runs headless automatically on the Pi (no $DISPLAY or
    onnx backend; --gui forces preview, --headless forces off). Headless:
    - no cv2 window/imshow/waitKey; the loop pushes annotated JPEGs to the
    webapp and paces with sleep.
    - alignment is phone-driven: webapp /align streams the live feed + green
    tray outline (MJPEG /stream.mjpg), operator taps Confirm
    (alignment_check_web).
    - Reje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
    [dice_tracker.py, webapp.py]
2026-06-14 Decide ground consolidation: 2.54mm common-bus pin board
    ~10 ground wires, all 26-28 AWG Dupont. WAGO 221 rejected (24 AWG min,
    too thin to seat); chose a 2.54mm common-rail bus board so every ground
    Dupont plugs on with no cutting/soldering and only one Pi GND pin is
    used. Spec + portability caveats recorded in DESIGN.md.
2026-06-14 Finalize ground bus: mini breadboard (no HAT, case is set)
    Case is already printed and has internal room; HAT rejected (too tall,
    covers header). Final: a mini self-adhesive breadboard as the common
    ground rail -- one Pi GND jumper energizes a '-' rail, all 10 ground
    Duponts plug in, stays fully plug-in/no-solder. '+' rail can also bus
    the OLED 3V3. Supersedes the earlier 2.54mm bus-board note.
2026-06-14 Lock ground-bus part: REXQualis 400-point self-adhesive breadboard
    Listing confirms the three musts: power rails on both ends (the bus),
    self-adhesive backing (mount), and 20-29 AWG support (covers 26-28 AWG
    Dupont). 170-point minis rejected (no rails). Parts decision closed.
2026-06-14 Ground-bus breadboard ordered (committed)
    Mark the 400-point self-adhesive breadboard as ordered, not just chosen.
    Last open hardware-parts decision is now closed.
2026-06-14 Defer standalone touchscreen (no-phone mode) to post-bring-up
    User goal: rig usable without a phone. Confirmed the existing web app
    (live read, dice switching, BB3 roll record) would run touch-operable on
    a 5" HDMI screen via browser kiosk -- ~free in software. Deferred because
    blockers are physical: sealed case has no cutout, two-player ergonomics
    vs the per-player OLEDs, ~5V/2A battery hit. Plan: finish + prove the
    OLED/button/phone build first, then evaluate against a working rig.
    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
2026-06-14 Resolve table touchscreen plan: standalone accessory, self-powered
    User found a 7" ELECROW screen WITH STAND -- sits at the table, not in
    the case. This makes it additive (OLEDs + buttons + phone all stay) and
    removes every prior blocker: no case cutout, two-player ergonomics
    unaffected, battery opt-in. Board has a dedicated Power port -> power
    from the bank directly, not through the Pi (no brown-out). Software is
    just a boot kiosk to localhost:5000. Build after the rig is proven.
2026-06-14 Touchscreen: capture vendor power-port + Pi4 config notes
    Listing detail confirms the self-power requirement (power via dedicated
    Power port, NOT the USB-touch port, or touch breaks; speakers need it at
    >=80% vol), that screen and Pi are independently powered (protects the
    Pi/camera), and a Pi4 Bullseye config.txt line (dtoverlay=vc4-kms-v3d)
    for the eventual kiosk setup. Package ships complete with stand.
2026-06-15 Grounds direct to Pi pins via splitters (breadboard not needed)
    During wiring: grounds go direct to the Pi's 8 ground pins using 1-to-2
    Dupont splitters rather than a breadboard rail -- fewer friction joints
    for a sealed portable rig, and the ground pins have no other use. OLED
    grounds = pin 25 -> splitter -> both OLEDs. Breadboard becomes optional
    (spare / 3V3 rail). DESIGN.md ground section revised; breadboard option
    retained as fallback.
2026-06-16 setup_pi.sh: tolerate missing apt packages (Trixie libatlas removal)
    libatlas-base-dev was retired on Debian Trixie, which aborted the whole
    setup under set -e. Install apt packages one at a time so a missing/
    renamed package is skipped with a note instead of halting; swap
    libatlas-base-dev -> libopenblas0 (its Trixie replacement). BLAS is
    optional anyway -- the ARM numpy/onnxruntime wheels bundle their own.
2026-06-16 Add deploy/hw_selftest.py: actively drive OLEDs + LEDs
    hardware.py's self-test only checks libs + button presses; it never
    lights the OLEDs/LEDs, so blank screens there are expected not failure.
    This test writes to both OLEDs and blinks each LED in turn so the
    display + LED wiring can be verified on the bench.
    [hw_selftest.py]
2026-06-16 Add deploy/oled2_test.py: drive only OLED-2 to wiggle-test loose CS
    P2 OLED initialized then dropped out mid-run (P1 stayed lit) = intermittent
    CS connection on OLED-2 (CE1/pin26). This loops a counter on OLED-2 only so
    the purple CS wire + splitters can be wiggle-tested for flicker/recovery.
    [oled2_test.py]
2026-06-16 Add deploy/oled1_test.py: drive only OLED-1 (CE0/pin24) for swap check
    Pairs with oled2_test.py to confirm which physical screen maps to which
    chip-select and that both CS lines work, after P2(CE1) tested good.
    [oled1_test.py]
2026-06-16 Web UI: add Align to nav, make header full-width sticky tap buttons
    The phone had no link to /align (had to type the URL), and the Live/Games
    header links were small text. Add Align to the shared header and restyle
    the three links as evenly-split, sticky, tap-friendly buttons so you can
    move Align <-> Live <-> Games with one tap on any page. Layout-only;
    no detection/hardware change.
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2026-06-16 Fix d16 settle: gate on cluster count, not flickering glyph-box count
    d16 wouldn't settle live: a die's 2-3 glyph faces each flicker in/out at
    the conf threshold every frame, so len(stable_ids) thrashed 2<->3 and the
    "identical for 10 frames" window reset forever. Gate on the DICE/cluster
    count instead (a resting die is one cluster regardless of how many faces
    are seen this frame) and require >=2 stable faces (enough for the
    adjacency layer to deduce the top). Add DICE_DEBUG=1 diagnostics + the
    missing os import.
    [dice_tracker.py]
2026-06-16 Settle is now FPS-adaptive (~0.5s) instead of fixed 10 frames
    d16/block settle felt sluggish (~2s) on the Pi: COUNT_STABLE_FRAMES=10 is
    a FRAME count, and the Pi's CPU-only onnxruntime runs ~5fps vs the PC's
    ~30fps, so 10 frames stretched to ~2s. Measure real capture FPS during
    the startup warm-up and derive settle_frames = round(SETTLE_SECONDS *
    fps), floored at 4 so a brief flicker can't settle a moving die. Prints
    the measured fps + derived frame count at startup. eval_harness keeps the
    fixed 10 (runs on PC at ~30fps). Tune feel via SETTLE_SECONDS (0.5).
    [dice_tracker.py]
2026-06-16 Make Ctrl-C reliably stop the tracker (SIGINT flag)
    Ctrl-C often didn't stop the rig: a KeyboardInterrupt landing inside the
    blocking cap.read() on the slow Pi got swallowed, and there was no
    handler. Install a SIGINT handler that flips a stop flag the main loop
    checks each frame, so the loop exits cleanly and runs camera/GPIO
    cleanup. (pkill -f dice_tracker.py from a 2nd SSH session also works.)
    Rolls are already persisted to the DB at confirm-time, so Ctrl-C loses no
    logged data.
    [dice_tracker.py]
2026-06-16 Add deploy/oled_both_test.py: drive BOTH OLEDs with distinct text
    Single-run diagnostic: CE0/pin24 shows P1, CE1/pin26 shows P2, each on
    its own chip-select. Distinguishes a CS swap vs a shared/floating CS vs a
    dead panel at a glance, instead of running the two single-screen tests
    separately.
    [oled_both_test.py]
2026-06-16 Fix oled_both_test: second device must not re-pulse shared RST
    Both panels share RST (GPIO25). When both ssd1309 constructors claim
    gpio_RST=25, building the second device resets the first panel right
    after it initialized, leaving the first screen blank in the dual test
    (while each single-screen test works fine, since nothing resets it after).
    Only the first device drives the shared reset now; the second uses
    gpio_RST=None.
    [oled_both_test.py]
2026-06-16 Fix P1 OLED blank in live app: second device must not re-pulse shared RST
    hardware.py built both ssd1309 devices with gpio_RST=GPIO25. Since RST is
    shared, constructing device 1 (CE1/P2) reset device 0 (CE0/P1) right
    after it initialized, leaving the P1 (left) screen blank on the rig while
    P2 worked. This is the root cause of the "Player 1 OLED not working"
    symptom -- not the wiring or the panel (both proven good via
    oled_both_test.py). Only the first device drives the shared reset now.
    [hardware.py]
2026-06-16 Phone tap-4-corners tray re-calibration on /align
    Camera moves between sessions (e.g. new case), so the saved tray_roi.json
    green outline no longer matches the tray. Add a phone-only recalibration:
    on /align, tap "Re-set corners", tap the tray's 4 corners (TL,TR,BR,BL),
    Save. The corners post to /api/align_corners; the tracker's headless
    alignment loop rewrites tray_roi.json (quad for the overlay + its
    axis-aligned bbox for the inference crop) and the live overlay updates on
    the next frame. crop_rect is recomputed after alignment so detection uses
    the new ROI, not the stale one captured before alignment ran.
    Keeps the existing rectangular-crop model — no perspective warp, no
    retrain. Stra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
    [dice_tracker.py, webapp.py]
2026-06-16 /align: show "session running" notice once live (alignment is startup-only)
    After Confirm, the alignment overlay loop exits and the MJPEG stream
    carries the live read, so the Align tab showed a confusing blank/broken
    image mid-session. Add a WebControl.aligning flag (set while the startup
    alignment loop streams the outline, cleared on confirm) and an
    /api/align_state endpoint. The /align page now checks it on load: during
    alignment it shows the tap-4-corners UI and opens the stream; once a
    session is running it shows a notice that alignment is startup-only and
    how to re-align (restart the service). The stream is only opened while
    aligning, so a live session has no phantom stream client on th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
    [dice_tracker.py, webapp.py]
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2026-06-16 CHEATSHEET: add phone workflows (align, IR mode, clear games)
    Document the three phone tabs in one place: startup-only alignment +
    tap-4-corners re-calibration, the always-IR rule and how to verify it
    (day-mode warning = real problem), and clearing games (per-game delete /
    Clear all, with the active game protected).
2026-06-17 Regenerate wiring diagram: full Pi pinout + correct button colors
    New primary diagram (Higgsfield nano_banana_pro) draws the real 40-pin Pi
    header pinout and the confirmed button wire colors (P1=blue, P2=green,
    Reject=red, Undo=yellow, grounds white). Verified every GPIO/pin label +
    the header pinout against DESIGN.md + the official Pi pinout -- no
    hallucinated pins (the old "GND Pin 7" error is gone). README refreshed;
    stale Pin-7 caveat removed.
2026-06-17 Games UI: pin editable latest roll, names form, Started/Export to bottom
    Game-detail page (/games/<id>): the latest roll is now pinned at the very
    top in a highlighted card with its fix panel open, so the most common task
    (correcting the most recent read) is the first thing on screen. Started +
    Export CSV moved below the roll log. Full log still shows newest-first.
    Auto-refresh ignores the pinned card's always-open fix panel but still
    holds while a manual panel is open or a field is focused.
    Games list: added a "Player names" form (P1/P2) at the top. Saving posts
    to /games/names -> WebControl.request_names; the tracker applies them to
    the session (so the NEXT game uses them) and renames the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
    [dice_tracker.py, webapp.py]
2026-06-18 Games: import coach/team names from Blood Bowl Game Sheets (TourPlay)
    Add tourplay.py: fetches league fixtures (teams + coaches) via the SAME
    Cloudflare Worker proxy the Game Sheets site uses. Direct tourplay.net
    calls return 403 (bot protection); the Worker
    (bb-gamesheet-app.chapman-thor.workers.dev) proxies /api/* with the right
    origin. Parses phases?...&round=N -> matches[].rosterLocal/Visitor exactly
    as the site does (coach at inscription.player.userNameToShow, race via
    _BB2025 strip). Verified live: 90 matches, round 10, correct coaches.
    Games tab gets a "Load from Game Sheets" block: paste the Game Sheets URL
    (slug + phaseId), Fetch matches, pick round -> pick match, and it fills the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
    [tourplay.py, webapp.py]
2026-06-18 Stop committing wiring diagram PNGs (~23 MB) — they bloated Pi pulls
    The two wiring/*.png diagrams (12 MB + 11 MB) are build-PC reference
    material; the Pi never reads them. A leftover .gitignore override
    (!wiring/*.png) force-included them despite the global *.png ignore, so
    every pull on the rig had to drag 23 MB across the network — which caused
    fetch resets / early EOF on slow links (2026-06-17). Untrack them, remove
    the override so they follow the normal *.png ignore, and document why.
    Files stay on the build PC; regenerate from DESIGN.md's pin map if needed.
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2026-06-18 Add project showcase doc + BOM; track docs/, keep them off the Pi
    - DESIGN.md §6: replace the stale on-hand/on-order lists with the accurate
    as-built BOM (Dupont jumpers + splitters in; Bambu lamps, JST pigtails,
    heat-set inserts moved to "ordered but not used"; 7" screen as optional
    add-on with the 2x scaling note).
    - docs/: styled Word showcase (BB-Dice-Tracker-Showcase.docx) with the
    concept/rig/wiring/Fusion/Games/Live images embedded + a concept-to-
    assembly writeup and a Bill of Materials section. build_showcase.js
    regenerates it from the images in docs/.
    - .gitignore: track docs/ (doc + its images) as an exception to the global
    image ignore; ignore node_modules/ and pac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
2026-06-28 Docs: capture the 2026-06-27 session (connectivity, 7" screen, UX, risks)
    HANDOFF.md: new "SESSION 2026-06-27 — CURRENT STATE" section at the top —
    the three ways to reach the rig (WiFi / Bluetooth PAN / Tailscale) with
    addresses and gotchas, the 7" screen 2x scaling, the software shipped this
    session (P1 OLED shared-RST fix, OLED confirmed-state, tap-4-corners,
    Games tab rework + Game Sheets import, showcase doc + BOM, repo hygiene),
    and the OPEN ITEMS: overheating risk, sparse-checkout not yet set up on
    the Pi, day-mode-on-startup, password-in-transcript.
    CHEATSHEET.md: lowercase-username note + PowerShell ssh full-path tip; a
    "reach the rig three ways" table (Tailscale 100.72.200.96,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
